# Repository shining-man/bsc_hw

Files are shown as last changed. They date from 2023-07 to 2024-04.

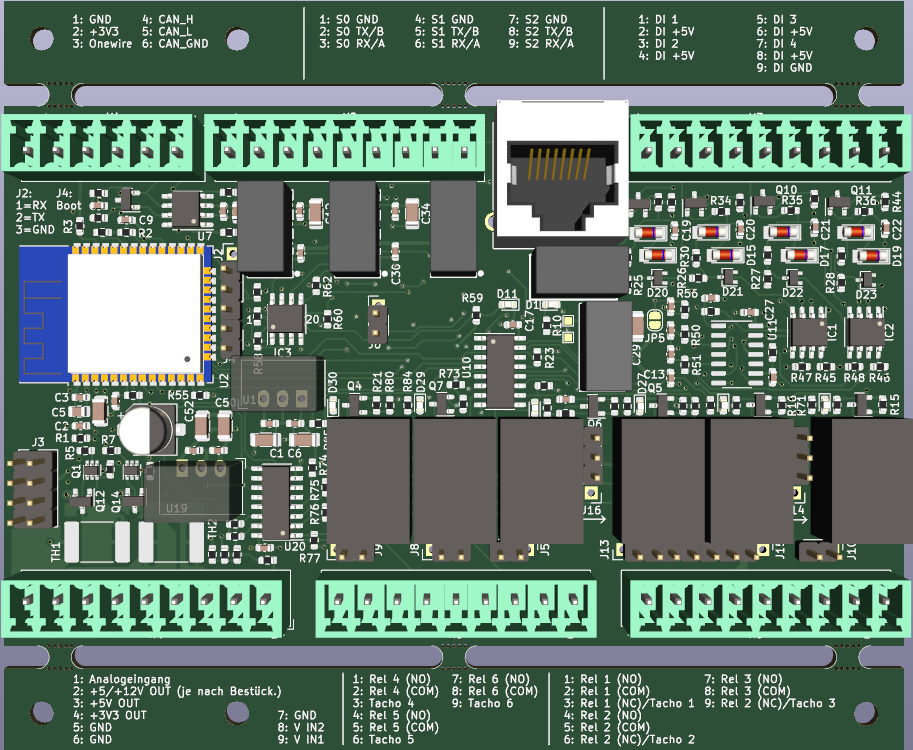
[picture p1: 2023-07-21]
img/bsc_3d.png

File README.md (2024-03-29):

# Battery safety controller (BSC)
This is the PCB for the Battery safety controller.<br>
More information in the wiki and in the discussions of the bsc_fw project.<br>
[BSC Project](https://github.com/shining-man/bsc_fw)<br>
[Wiki (German)](https://github.com/shining-man/bsc_fw/wiki)<br>
[Discussions](https://github.com/shining-man/bsc_fw/discussions)<br>
<br>
BSC_HW_TOP
BSC_HW_BOTTOM

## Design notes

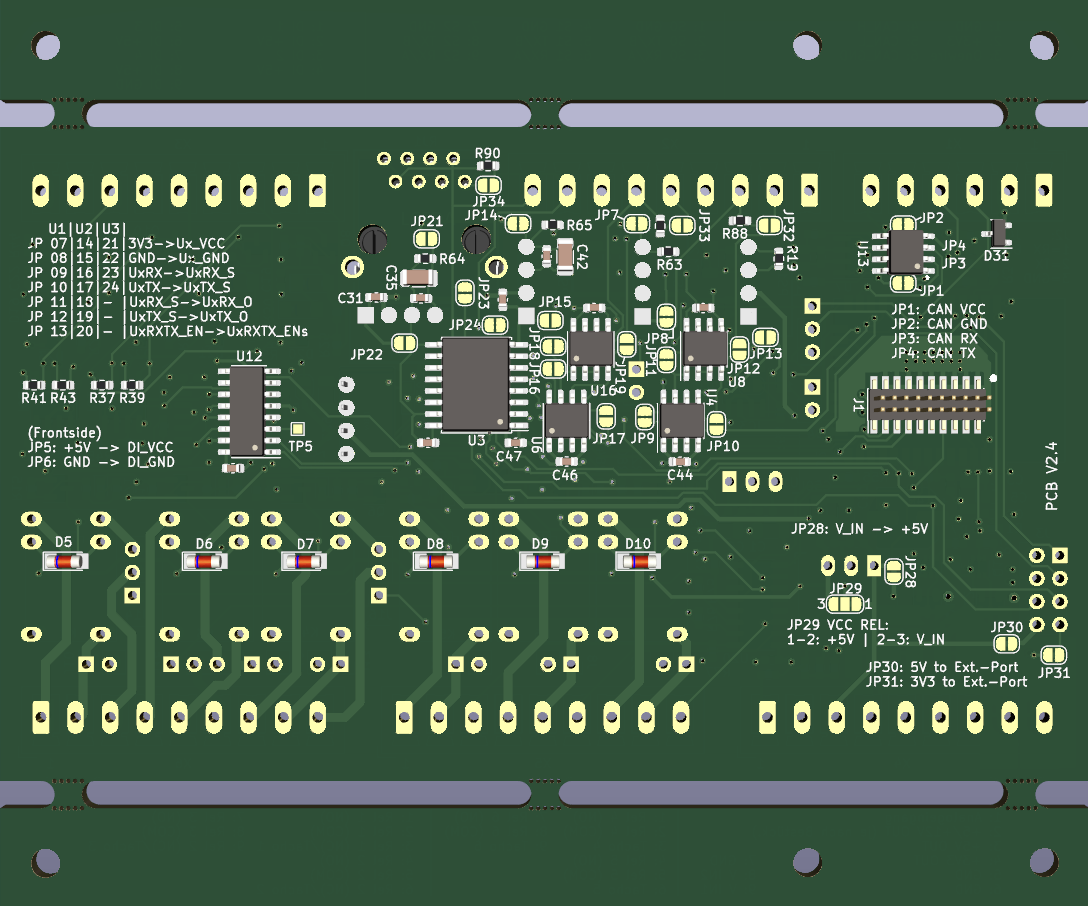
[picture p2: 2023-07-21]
img/bsc_bot.png

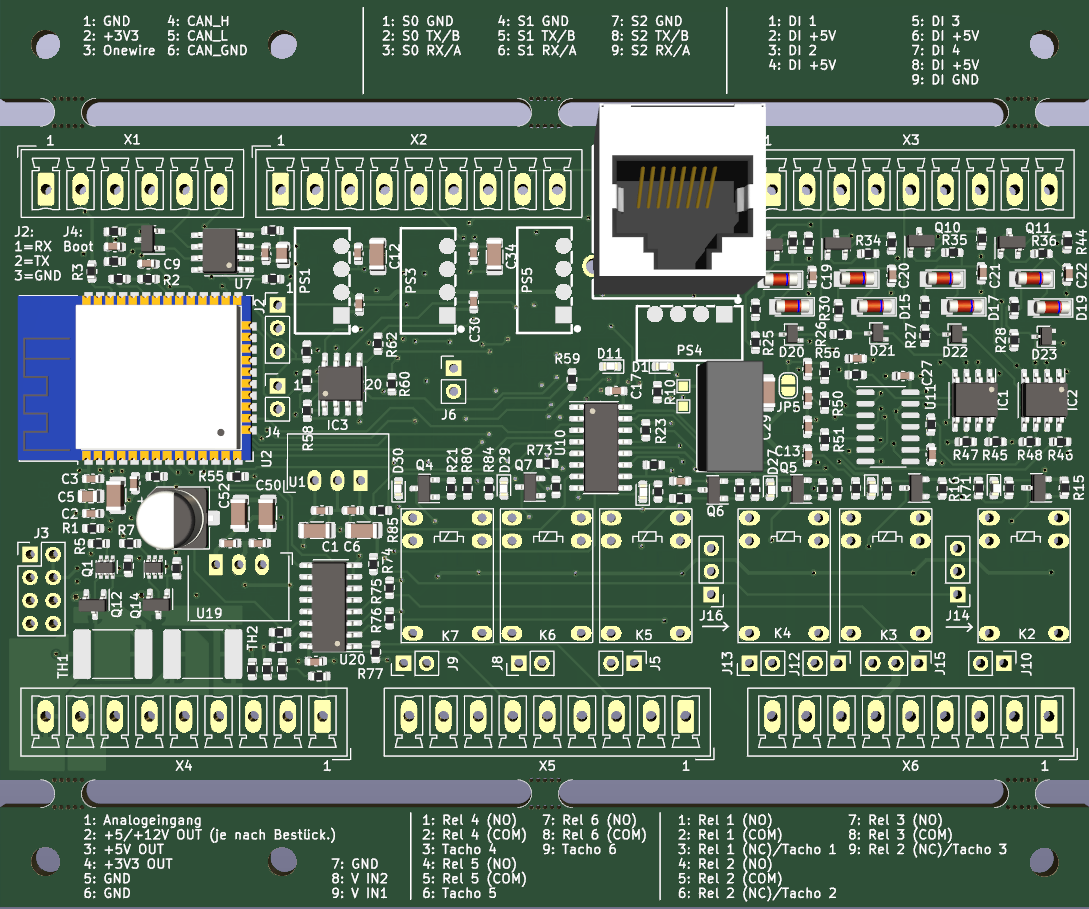
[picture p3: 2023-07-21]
img/bsc_top.png

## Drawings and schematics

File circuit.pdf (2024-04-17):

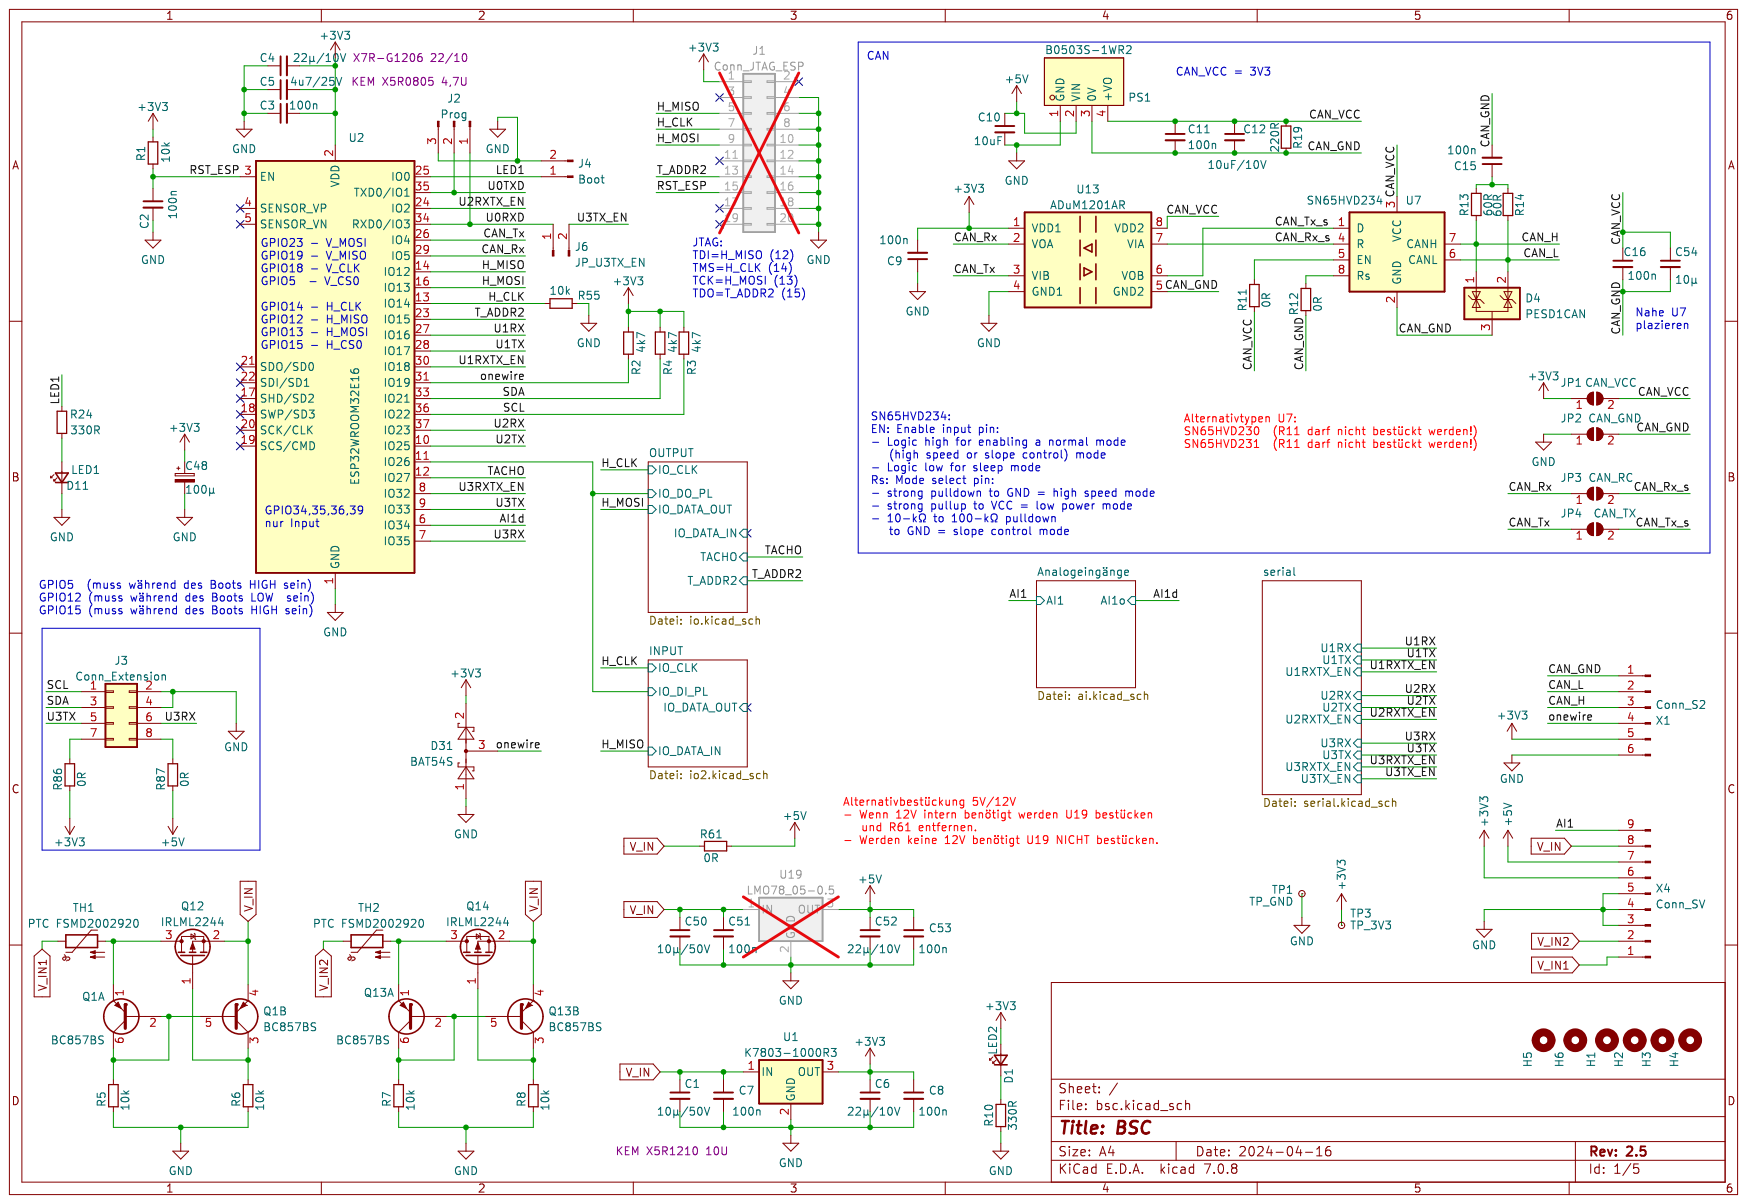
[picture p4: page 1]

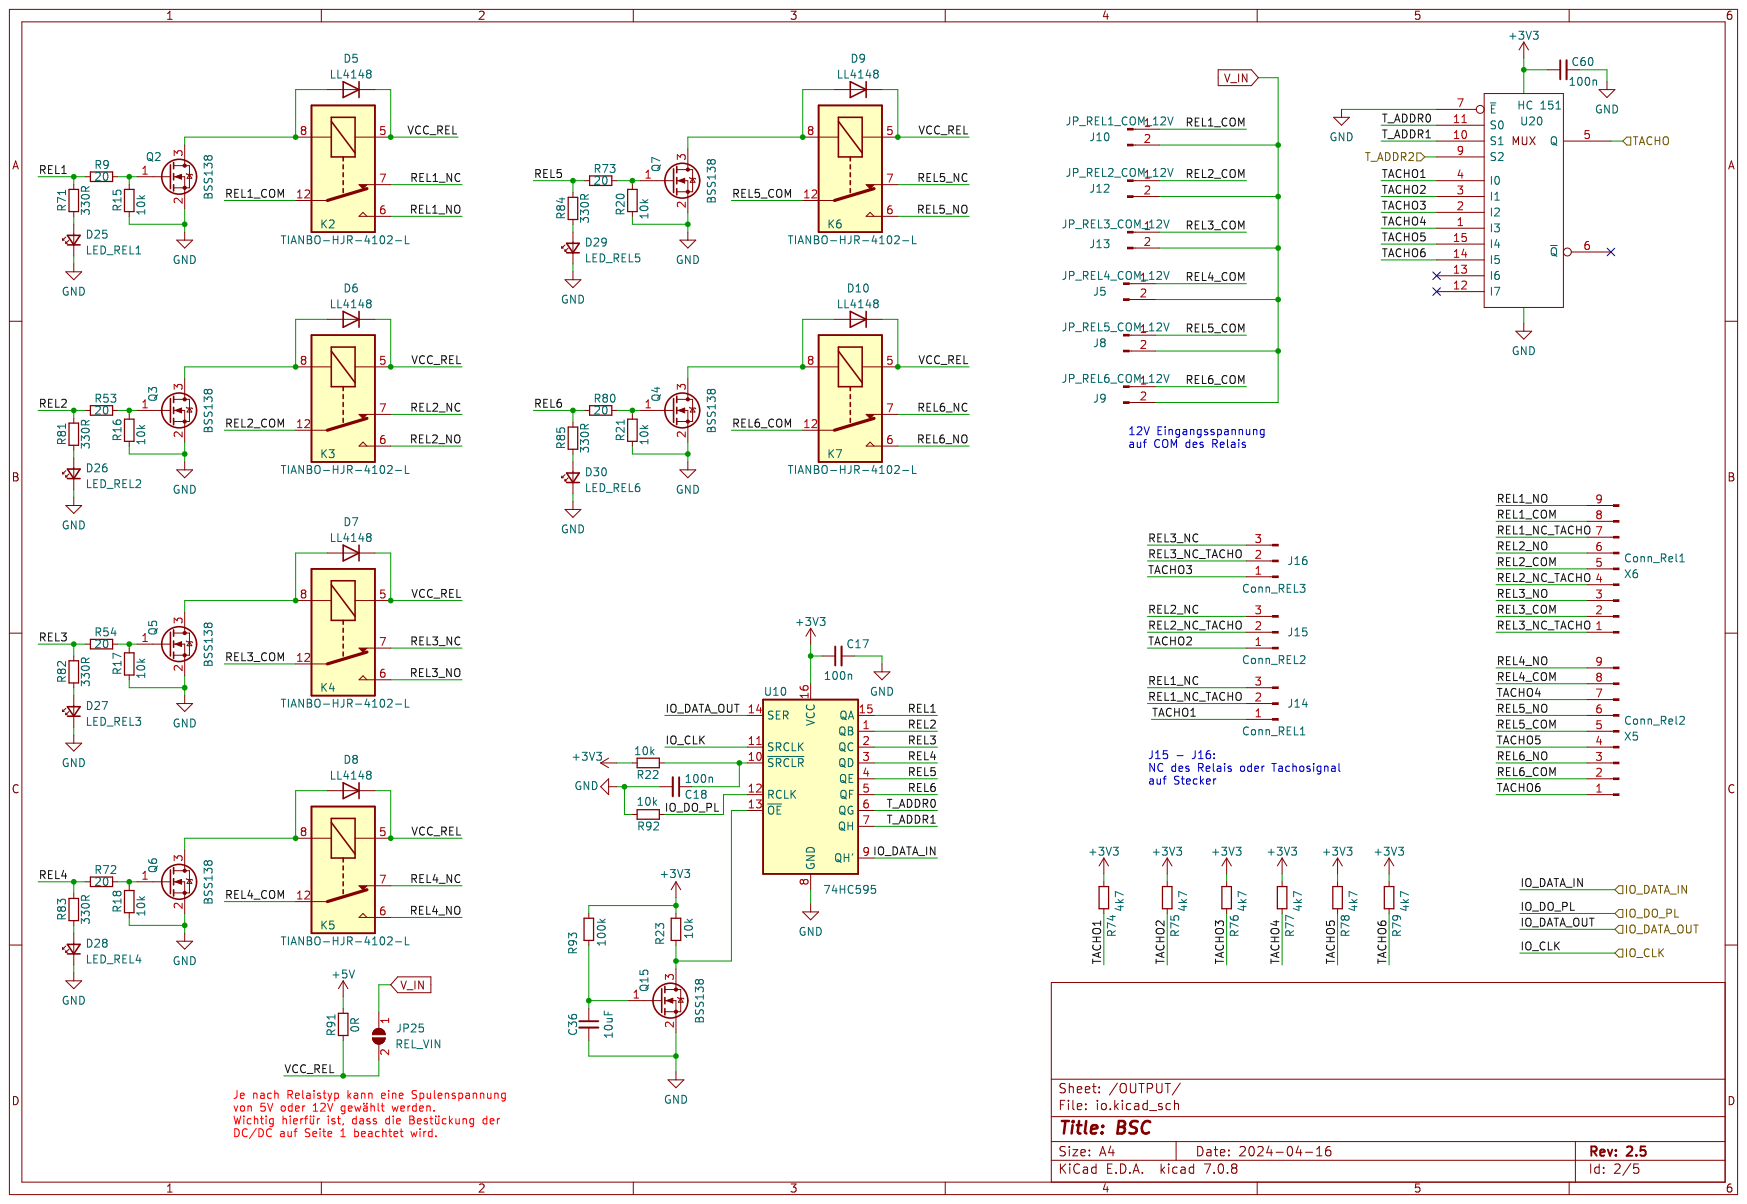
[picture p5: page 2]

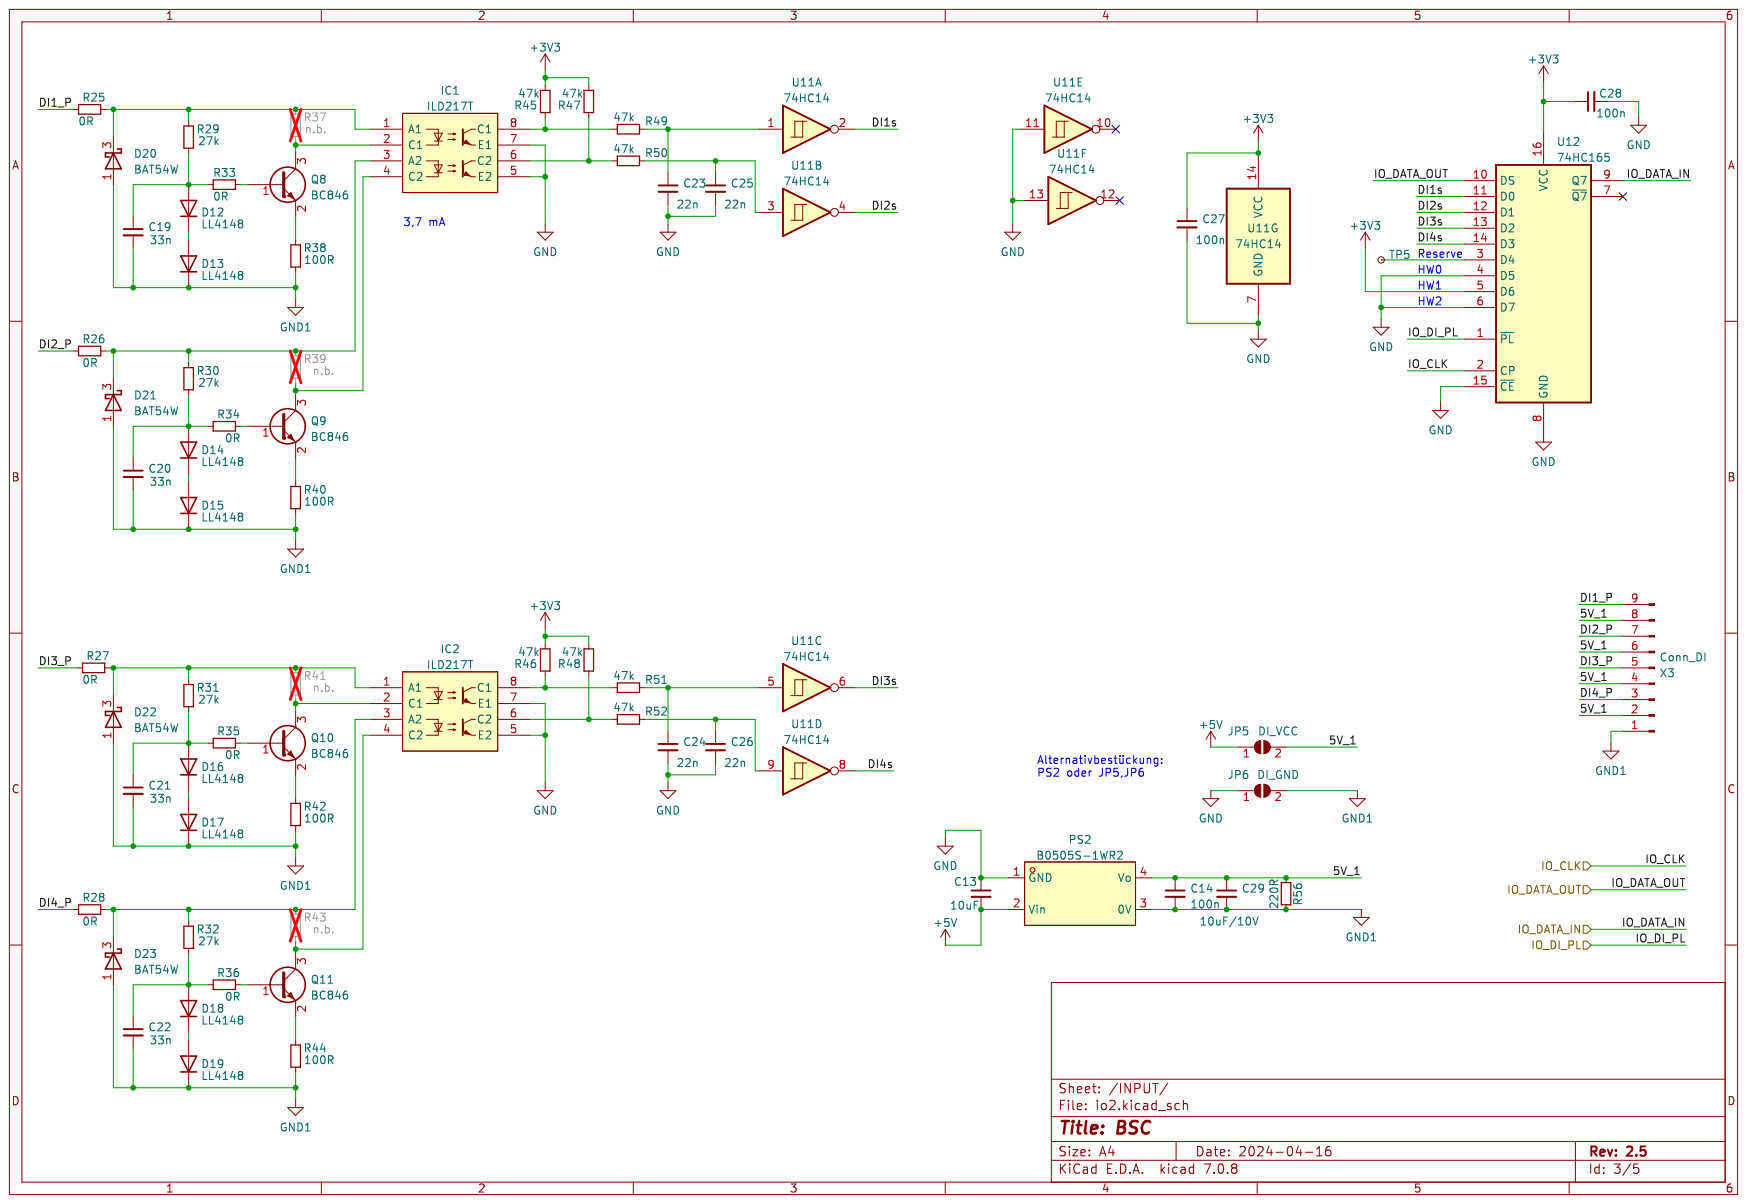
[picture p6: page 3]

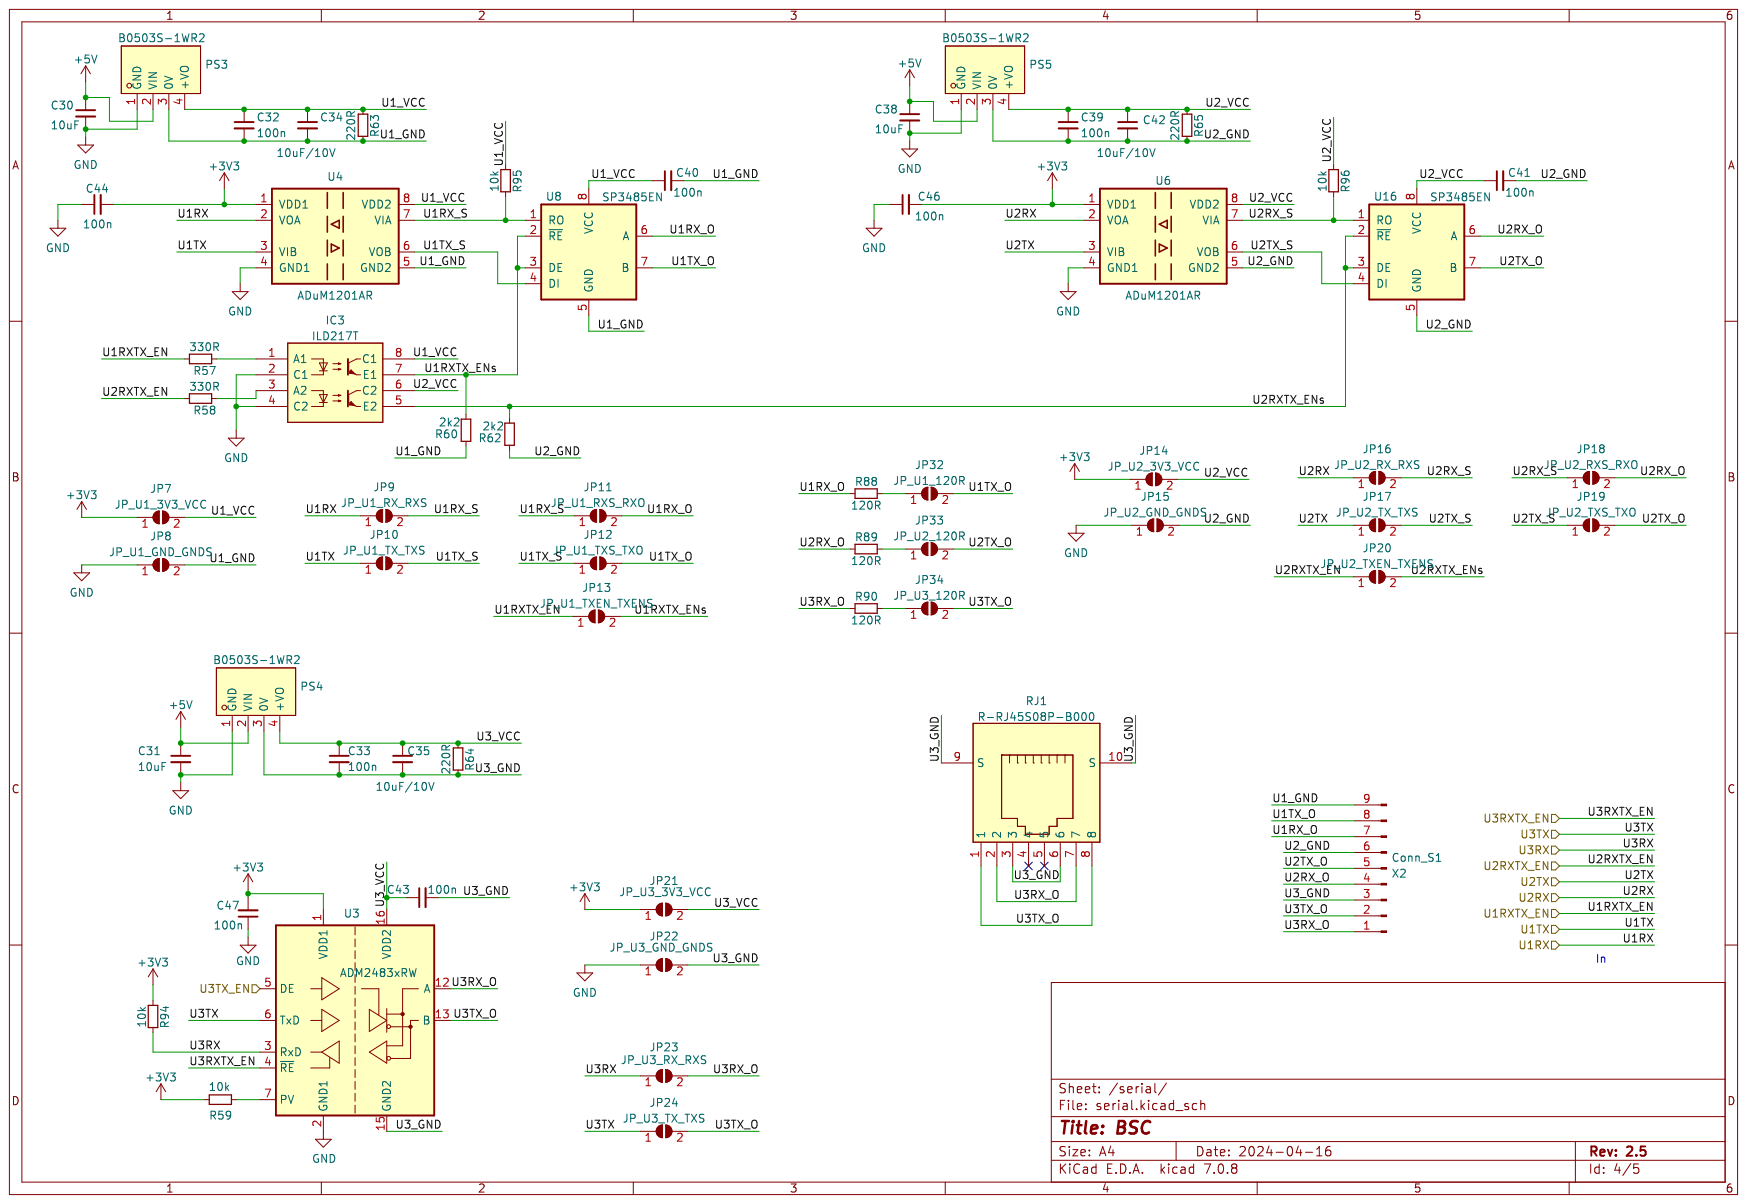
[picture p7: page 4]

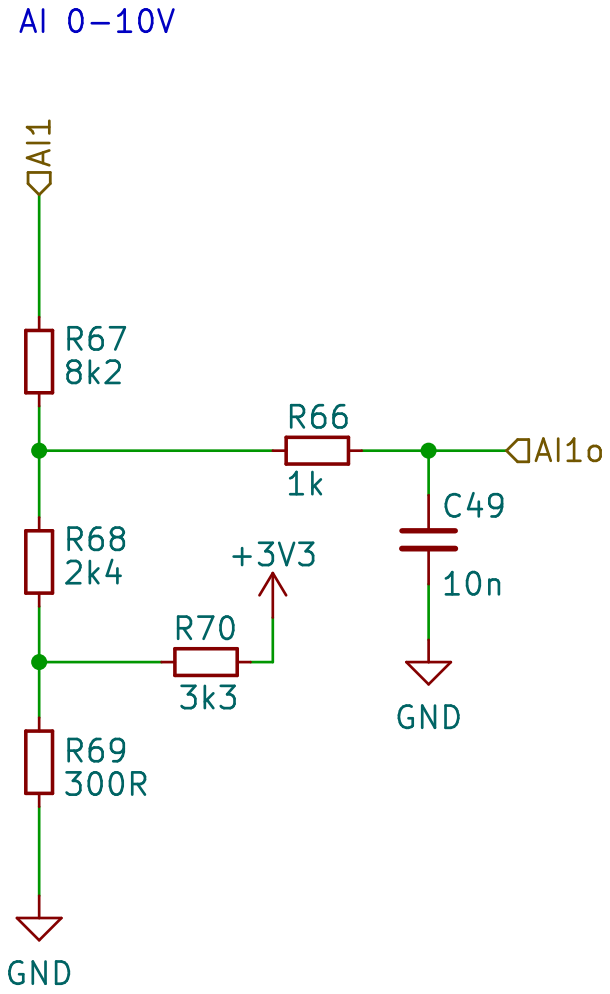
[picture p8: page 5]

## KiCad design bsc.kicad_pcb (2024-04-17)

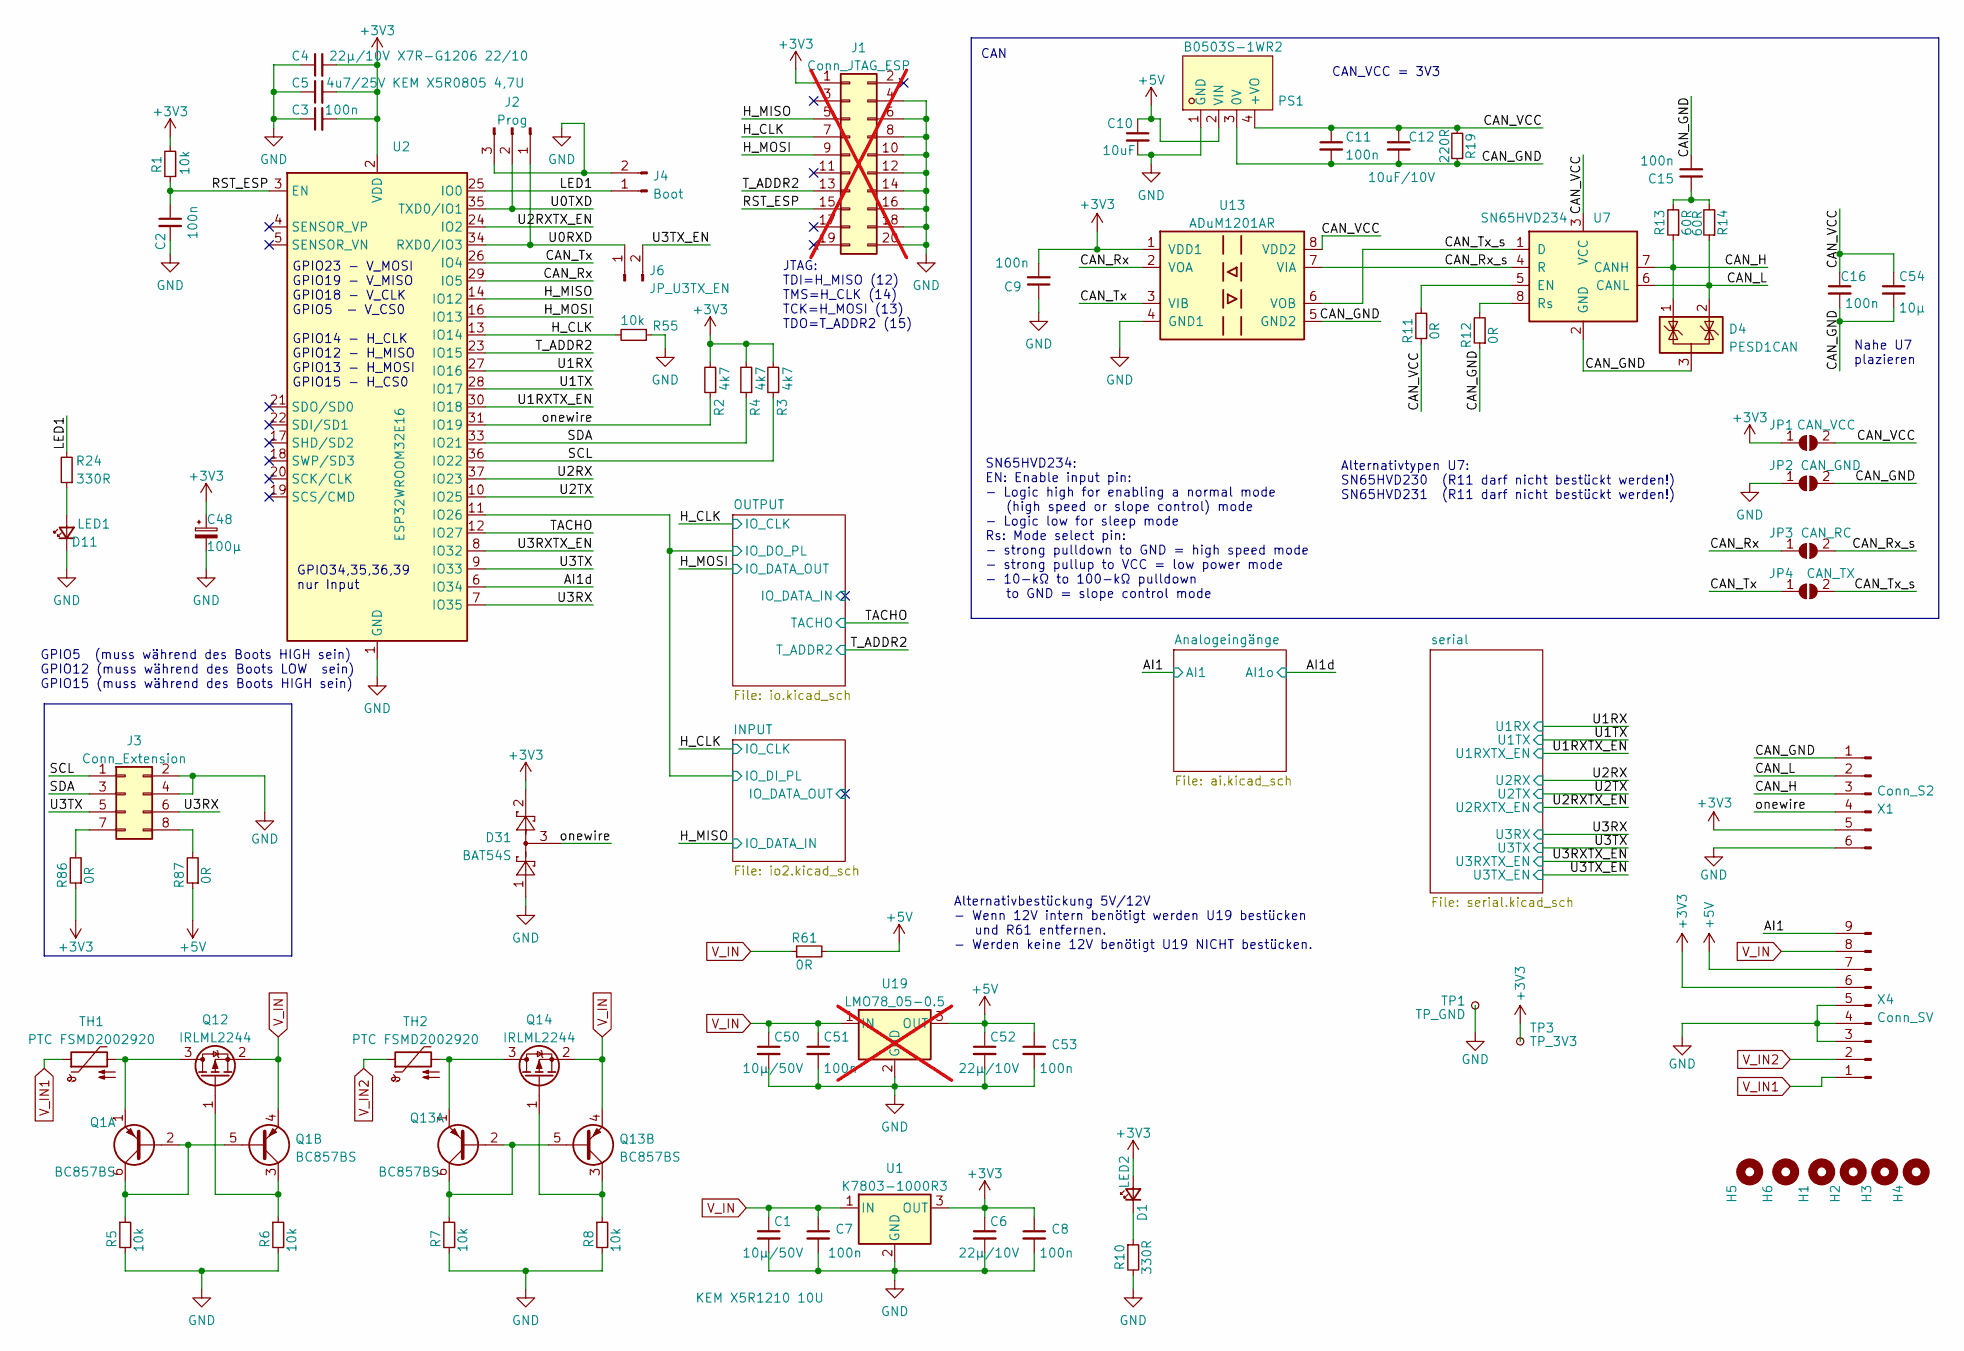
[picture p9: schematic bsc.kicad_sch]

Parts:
C1, C50: 10µ/50V; C_1206_3216Metric
C2, C3, C7, C8, C9, C11, C15, C16, C51, C53: 100n; C_0603_1608Metric
C4, C6, C52: 22µ/10V; C_1206_3216Metric
C5: 4u7/25V; C_0805_2012Metric
C10: 10uF; C_0603_1608Metric
C12: 10uF/10V; C_1206_3216Metric
C48: 100µ; CP_Elec_6.3x5.9
C54: 10µ; C_0805_2012Metric
D1: LED2; LED_0603_1608Metric
D4: PESD1CAN; SOT-23
D11: LED1; LED_0603_1608Metric
D31: BAT54S; SOT-23
H1, H2, H3, H4, H5, H6: MountingHole; MountingHole_3.2mm_M3
J1: Conn_JTAG_ESP; PinHeader_2x10_P1.27mm_Vertical_SMD; not fitted
J2: Prog; PinHeader_1x03_P2.54mm_Vertical_jlc
J3: Conn_Extension; PinHeader_2x04_P2.54mm_Vertical_jlc
J4: Boot; PinHeader_1x02_P2.54mm_Vertical_jlc
J6: JP_U3TX_EN; PinHeader_1x02_P2.54mm_Vertical_jlc
JP1: CAN_VCC; SolderJumper-2_P1.3mm_Open_RoundedPad1.0x1.5mm
JP2: CAN_GND; SolderJumper-2_P1.3mm_Open_RoundedPad1.0x1.5mm
JP3: CAN_RC; SolderJumper-2_P1.3mm_Open_RoundedPad1.0x1.5mm
JP4: CAN_TX; SolderJumper-2_P1.3mm_Open_RoundedPad1.0x1.5mm
PS1: B0503S-1WR2; PWRM-TH_DEXU_BXXXXS-1WR2; LCSC Part C5127059
Q1, Q13: BC857BS; SOT-363_SC-70-6
Q12, Q14: IRLML2244; SOT-23
R1, R5, R6, R7, R8, R55: 10k; R_0603_1608Metric
R2, R3, R4: 4k7; R_0603_1608Metric
R10, R24: 330R; R_0603_1608Metric
R11, R12, R61, R86, R87: 0R; R_0603_1608Metric
R13, R14: 60R; R_0603_1608Metric
R19: 220R; R_0805_2012Metric
TH1, TH2: PTC FSMD2002920; Fuse_2920_7451Metric
TP1: TP_GND; TestPoint_Pad_1.0x1.0mm
TP3: TP_3V3; TestPoint_Pad_1.0x1.0mm
U1: K7803-1000R3; Converter_DCDC_RECOM_R-78E-1.0; LCSC Part C111278
U2: ESP32WROOM32E16; ESP32-WROOM-32
U7: SN65HVD234; SOIC-8_3.9x4.9mm_P1.27mm
U13: ADuM1201AR; SOIC-8_3.9x4.9mm_P1.27mm
U19: LMO78_05-0.5; Converter_DCDC_RECOM_R-78E-1.0; not fitted
X1: Conn_S2; PhoenixContact_MCV_1,5_6-G-3.81_1x06_P3.81mm_Vertical
X4: Conn_SV; PhoenixContact_MCV_1,5_9-G-3.81_1x09_P3.81mm_Vertical

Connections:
+3V3: C3.2, C4.2, C5.2, C6.1, C8.1, C9.2, C48.1, D1.2 (A), D31.2, J1.1, JP1.1 (A), R1.2, R2.2, R3.2, R4.2, R86.1, TP3.1, U1.3 (OUT), U2.2 (VDD), U13.1 (VDD1), X1.5, X4.6; also elsewhere on the board
+5V: C10.1, C52.1, C53.1, PS1.2 (VIN), R61.2, R87.1, U19.3 (OUT), X4.7; also elsewhere on the board
/AI1: X4.9; also elsewhere on the board
/AI1d: U2.6 (IO34); also elsewhere on the board
/CAN_GND: C11.2, C12.2, C15.2, C16.2, C54.2, D4.3 (A), JP2.2 (B), PS1.3 (0V), R12.1, R19.1, U7.2 (GND), U13.5 (GND2), X1.1
/CAN_H: D4.1 (K), R13.1, U7.7 (CANH), X1.3
/CAN_L: D4.2 (K), R14.1, U7.6 (CANL), X1.2
/CAN_Rx: JP3.1 (A), U2.29 (IO5), U13.2 (VOA)
/CAN_Rx_s: JP3.2 (B), U7.4 (R), U13.7 (VIA)
/CAN_Tx: JP4.1 (A), U2.26 (IO4), U13.3 (VIB)
/CAN_Tx_s: JP4.2 (B), U7.1 (D), U13.6 (VOB)
/CAN_VCC: C11.1, C12.1, C16.1, C54.1, JP1.2 (B), PS1.4 (+VO), R11.1, R19.2, U7.3 (VCC), U13.8 (VDD2)
/H_CLK: J1.7, R55.2, U2.13 (IO14); also elsewhere on the board
/H_MISO: J1.5, U2.14 (IO12); also elsewhere on the board
/H_MOSI: J1.9, U2.16 (IO13); also elsewhere on the board
/INPUT/IO_DI_PL: U2.11 (IO26); also elsewhere on the board
/LED1: J4.1, R24.2, U2.25 (IO0)
/SCL: J3.1, R3.1, U2.36 (IO22)
/SDA: J3.3, R4.1, U2.33 (IO21)
/TACHO: U2.12 (IO27); also elsewhere on the board
/T_ADDR2: J1.13, U2.23 (IO15); also elsewhere on the board
/U0RXD: J2.1, J6.1, U2.34 (RXD0/IO3)
/U0TXD: J2.2, U2.35 (TXD0/IO1)
/U1RX: U2.27 (IO16); also elsewhere on the board
/U1RXTX_EN: U2.30 (IO18); also elsewhere on the board
/U1TX: U2.28 (IO17); also elsewhere on the board
/U2RX: U2.37 (IO23); also elsewhere on the board
/U2RXTX_EN: U2.24 (IO2); also elsewhere on the board
/U2TX: U2.10 (IO25); also elsewhere on the board
/U3RX: J3.6, U2.7 (IO35); also elsewhere on the board
/U3RXTX_EN: U2.8 (IO32); also elsewhere on the board
/U3TX: J3.5, U2.9 (IO33); also elsewhere on the board
/U3TX_EN: J6.2; also elsewhere on the board
/onewire: D31.3, R2.1, U2.31 (IO19), X1.4
GND: C1.2, C2.2, C3.1, C4.1, C5.1, C6.2, C7.2, C8.2, C9.1, C10.2, C48.2, C50.2, C51.2, C52.2, C53.2, D11.1 (K), D31.1, J1.4, J1.6, J1.8, J1.10, J1.12, J1.14, J1.16, J1.18, J1.20, J2.3, J3.2, J3.4, J4.2, JP2.1 (A), PS1.1 (GND), R5.2, R6.2, R7.2, R8.2, R10.2, R55.1, TP1.1, U1.2 (GND), U2.1 (GND), U2.15 (GND), U2.38 (GND), U2.39 (GND), U13.4 (GND1), U19.2 (GND), X1.6, X4.3, X4.4, X4.5; also elsewhere on the board
unnamed: C15.1, R13.2, R14.2
unnamed: D1.1 (K), R10.1
unnamed: D11.2 (A), R24.1
unnamed: J3.7, R86.2
unnamed: J3.8, R87.2
unnamed: Q1.2 (B1), Q1.5 (B2), Q1.6 (C1), R5.1
unnamed: Q1.1 (E1), Q12.3 (D), TH1.2
unnamed: Q1.3 (C2), Q12.1 (G), R6.1
unnamed: Q13.2 (B1), Q13.5 (B2), Q13.6 (C1), R7.1
unnamed: Q13.1 (E1), Q14.3 (D), TH2.2
unnamed: Q13.3 (C2), Q14.1 (G), R8.1
unnamed: R11.2, U7.5 (EN)
unnamed: R12.2, U7.8 (Rs)
V_IN: C1.1, C7.1, C50.1, C51.1, Q1.4 (E2), Q12.2 (S), Q13.4 (E2), Q14.2 (S), R61.1, U1.1 (IN), U19.1 (IN), X4.8; also elsewhere on the board
V_IN1: TH1.1, X4.1
V_IN2: TH2.1, X4.2

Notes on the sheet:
SN65HVD234: EN: Enable input pin: - Logic high for enabling a normal mode (high speed or slope control) mode - Logic low for sleep mode Rs: Mode select pin: - strong pulldown to GND = high speed mode - strong pullup to VCC = low power mode - 10-kΩ to 100-kΩ pulldown to GND = slope control mode
GPIO23 - V_MOSI GPIO19 - V_MISO GPIO18 - V_CLK GPIO5 - V_CS0 GPIO14 - H_CLK GPIO12 - H_MISO GPIO13 - H_MOSI GPIO15 - H_CS0
JTAG: TDI=H_MISO (12) TMS=H_CLK (14) TCK=H_MOSI (13) TDO=T_ADDR2 (15)
CAN
CAN_VCC = 3V3
Alternativtypen U7: SN65HVD230 (R11 darf nicht bestückt werden!) SN65HVD231 (R11 darf nicht bestückt werden!)
Nahe U7 plazieren
GPIO5 (muss während des Boots HIGH sein) GPIO12 (muss während des Boots LOW sein) GPIO15 (muss während des Boots HIGH sein)
Alternativbestückung 5V/12V - Wenn 12V intern benötigt werden U19 bestücken und R61 entfernen. - Werden keine 12V benötigt U19 NICHT bestücken.
GPIO34,35,36,39 nur Input

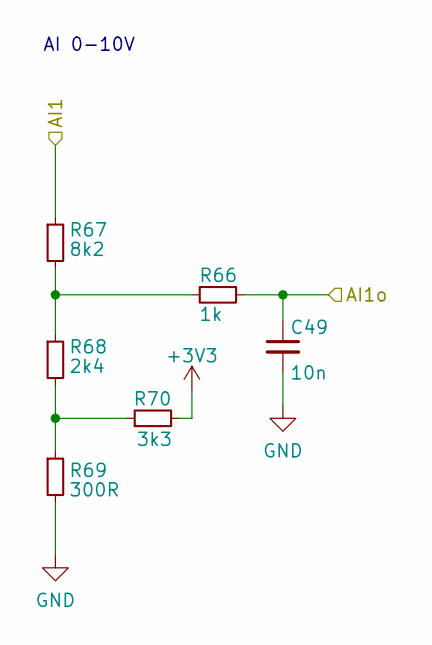
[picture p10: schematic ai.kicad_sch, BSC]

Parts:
C49: 10n; C_0603_1608Metric
R66: 1k; R_0603_1608Metric
R67: 8k2; R_0603_1608Metric
R68: 2k4; R_0603_1608Metric
R69: 300R; R_0603_1608Metric
R70: 3k3; R_0603_1608Metric

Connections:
+3V3: R70.2; also elsewhere on the board
/AI1: R67.1; also elsewhere on the board
/AI1d: C49.1, R66.1; also elsewhere on the board
GND: C49.2, R69.2; also elsewhere on the board
unnamed: R66.2, R67.2, R68.1
unnamed: R68.2, R69.1, R70.1

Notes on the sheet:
AI 0-10V

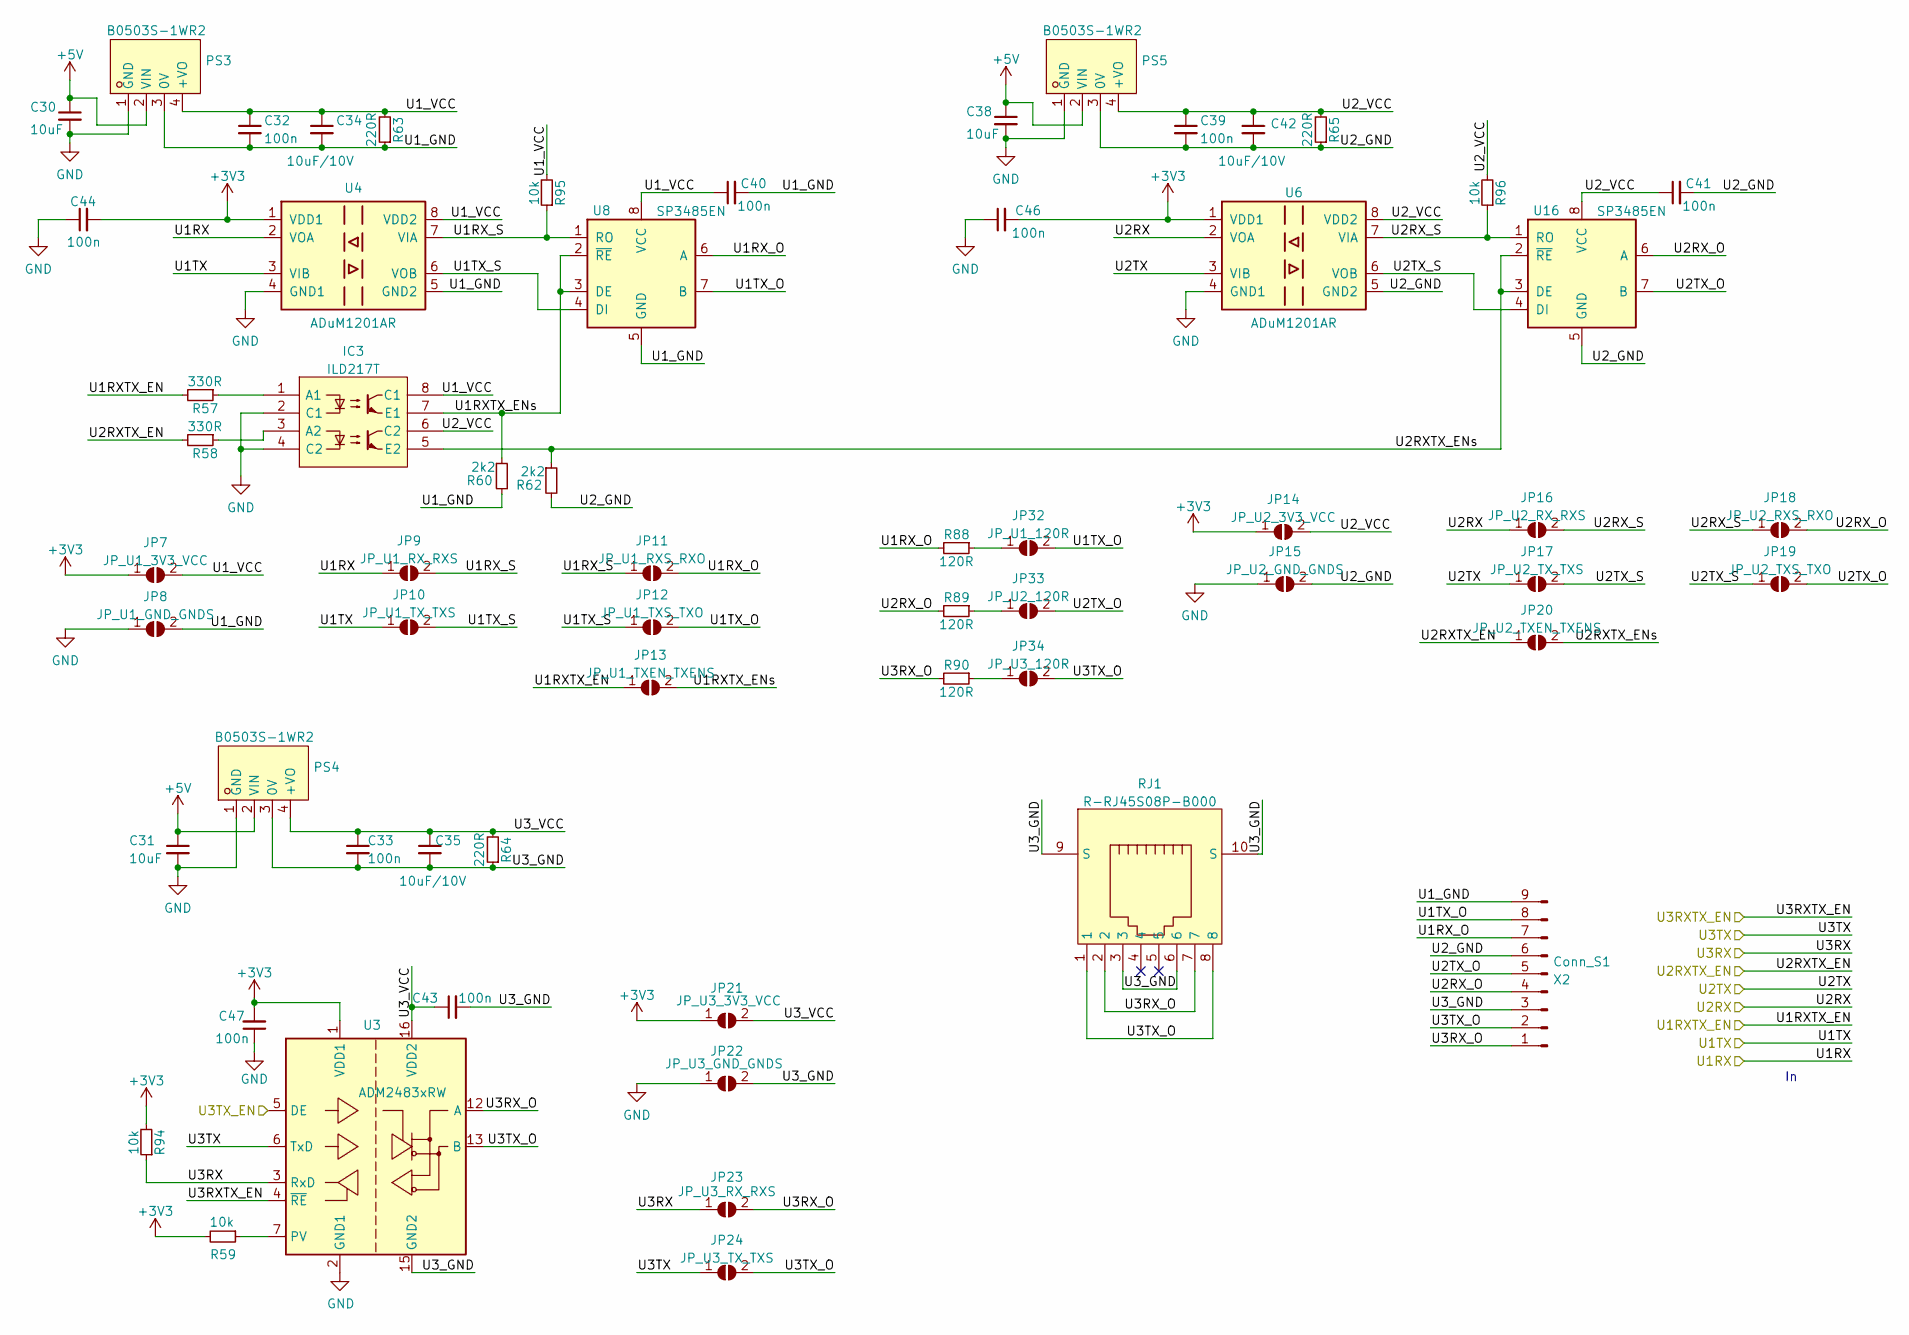
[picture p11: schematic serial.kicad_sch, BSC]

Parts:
C30, C31, C38: 10uF; C_0603_1608Metric
C32, C33, C39, C40, C41, C43, C44, C46, C47: 100n; C_0603_1608Metric
C34, C35, C42: 10uF/10V; C_1206_3216Metric
IC3: ILD217T; SOIC-8_3.9x4.9mm_P1.27mm; Mouser Part Number 782-ILD217T
JP7: JP_U1_3V3_VCC; SolderJumper-2_P1.3mm_Open_RoundedPad1.0x1.5mm
JP8: JP_U1_GND_GNDS; SolderJumper-2_P1.3mm_Open_RoundedPad1.0x1.5mm
JP9: JP_U1_RX_RXS; SolderJumper-2_P1.3mm_Open_RoundedPad1.0x1.5mm
JP10: JP_U1_TX_TXS; SolderJumper-2_P1.3mm_Open_RoundedPad1.0x1.5mm
JP11: JP_U1_RXS_RXO; SolderJumper-2_P1.3mm_Open_RoundedPad1.0x1.5mm
JP12: JP_U1_TXS_TXO; SolderJumper-2_P1.3mm_Open_RoundedPad1.0x1.5mm
JP13: JP_U1_TXEN_TXENS; SolderJumper-2_P1.3mm_Open_RoundedPad1.0x1.5mm
JP14: JP_U2_3V3_VCC; SolderJumper-2_P1.3mm_Open_RoundedPad1.0x1.5mm
JP15: JP_U2_GND_GNDS; SolderJumper-2_P1.3mm_Open_RoundedPad1.0x1.5mm
JP16: JP_U2_RX_RXS; SolderJumper-2_P1.3mm_Open_RoundedPad1.0x1.5mm
JP17: JP_U2_TX_TXS; SolderJumper-2_P1.3mm_Open_RoundedPad1.0x1.5mm
JP18: JP_U2_RXS_RXO; SolderJumper-2_P1.3mm_Open_RoundedPad1.0x1.5mm
JP19: JP_U2_TXS_TXO; SolderJumper-2_P1.3mm_Open_RoundedPad1.0x1.5mm
JP20: JP_U2_TXEN_TXENS; SolderJumper-2_P1.3mm_Open_RoundedPad1.0x1.5mm
JP21: JP_U3_3V3_VCC; SolderJumper-2_P1.3mm_Open_RoundedPad1.0x1.5mm
JP22: JP_U3_GND_GNDS; SolderJumper-2_P1.3mm_Open_RoundedPad1.0x1.5mm
JP23: JP_U3_RX_RXS; SolderJumper-2_P1.3mm_Open_RoundedPad1.0x1.5mm
JP24: JP_U3_TX_TXS; SolderJumper-2_P1.3mm_Open_RoundedPad1.0x1.5mm
JP32: JP_U1_120R; SolderJumper-2_P1.3mm_Open_RoundedPad1.0x1.5mm
JP33: JP_U2_120R; SolderJumper-2_P1.3mm_Open_RoundedPad1.0x1.5mm
JP34: JP_U3_120R; SolderJumper-2_P1.3mm_Open_RoundedPad1.0x1.5mm
PS3, PS4, PS5: B0503S-1WR2; PWRM-TH_DEXU_BXXXXS-1WR2; LCSC Part C5127059
R57, R58: 330R; R_0603_1608Metric
R59, R94, R95, R96: 10k; R_0603_1608Metric
R60, R62: 2k2; R_0603_1608Metric
R63, R64, R65: 220R; R_0805_2012Metric
R88, R89, R90: 120R; R_0603_1608Metric
RJ1: R-RJ45S08P-B000; RJ45-TH_R-RJ45S08P-B000; LCSC Part C386763
U3: ADM2483xRW; SOIC-16W_7.5x10.3mm_P1.27mm; PartNumber ADM2483BRWZ-REEL; LCSCStockCode C9637
U4, U6: ADuM1201AR; SOIC-8_3.9x4.9mm_P1.27mm
U8, U16: SP3485EN; SOIC-8_3.9x4.9mm_P1.27mm
X2: Conn_S1; PhoenixContact_MCV_1,5_9-G-3.81_1x09_P3.81mm_Vertical

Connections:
+3V3: C44.2, C46.2, C47.2, JP7.1 (A), JP14.1 (A), JP21.1 (A), R59.2, R94.2, U3.1 (VDD1), U4.1 (VDD1), U6.1 (VDD1); also elsewhere on the board
+5V: C30.1, C31.1, C38.1, PS3.2 (VIN), PS4.2 (VIN), PS5.2 (VIN); also elsewhere on the board
/U1RX: JP9.1 (A), U4.2 (VOA); also elsewhere on the board
/U1RXTX_EN: JP13.1 (A), R57.2; also elsewhere on the board
/U1TX: JP10.1 (A), U4.3 (VIB); also elsewhere on the board
/U2RX: JP16.1 (A), U6.2 (VOA); also elsewhere on the board
/U2RXTX_EN: JP20.1 (A), R58.2; also elsewhere on the board
/U2TX: JP17.1 (A), U6.3 (VIB); also elsewhere on the board
/U3RX: JP23.1 (A), R94.1, U3.3 (RxD); also elsewhere on the board
/U3RXTX_EN: U3.4 (~RE); also elsewhere on the board
/U3TX: JP24.1 (A), U3.6 (TxD); also elsewhere on the board
/U3TX_EN: U3.5 (DE); also elsewhere on the board
/serial/U1RXTX_ENs: IC3.7 (E1), JP13.2 (B), R60.1, U8.2 (~RE), U8.3 (DE)
/serial/U1RX_O: JP11.2 (B), R88.2, U8.6 (A), X2.7
/serial/U1RX_S: JP9.2 (B), JP11.1 (A), R95.1, U4.7 (VIA), U8.1 (RO)
/serial/U1TX_O: JP12.2 (B), JP32.2 (B), U8.7 (B), X2.8
/serial/U1TX_S: JP10.2 (B), JP12.1 (A), U4.6 (VOB), U8.4 (DI)
/serial/U1_GND: C32.2, C34.2, C40.2, JP8.2 (B), PS3.3 (0V), R60.2, R63.1, U4.5 (GND2), U8.5 (GND), X2.9
/serial/U1_VCC: C32.1, C34.1, C40.1, IC3.8 (C1), JP7.2 (B), PS3.4 (+VO), R63.2, R95.2, U4.8 (VDD2), U8.8 (VCC)
/serial/U2RXTX_ENs: IC3.5 (E2), JP20.2 (B), R62.1, U16.2 (~RE), U16.3 (DE)
/serial/U2RX_O: JP18.2 (B), R89.2, U16.6 (A), X2.4
/serial/U2RX_S: JP16.2 (B), JP18.1 (A), R96.1, U6.7 (VIA), U16.1 (RO)
/serial/U2TX_O: JP19.2 (B), JP33.2 (B), U16.7 (B), X2.5
/serial/U2TX_S: JP17.2 (B), JP19.1 (A), U6.6 (VOB), U16.4 (DI)
/serial/U2_GND: C39.2, C41.2, C42.2, JP15.2 (B), PS5.3 (0V), R62.2, R65.1, U6.5 (GND2), U16.5 (GND), X2.6
/serial/U2_VCC: C39.1, C41.1, C42.1, IC3.6 (C2), JP14.2 (B), PS5.4 (+VO), R65.2, R96.2, U6.8 (VDD2), U16.8 (VCC)
/serial/U3RX_O: JP23.2 (B), R90.2, RJ1.2, RJ1.7, U3.12 (A), X2.1
/serial/U3TX_O: JP24.2 (B), JP34.2 (B), RJ1.1, RJ1.8, U3.13 (B), X2.2
/serial/U3_GND: C33.2, C35.2, C43.2, JP22.2 (B), PS4.3 (0V), R64.1, RJ1.3, RJ1.6, RJ1.9 (S), RJ1.10 (S), U3.9 (GND2), U3.15 (GND2), X2.3
/serial/U3_VCC: C33.1, C35.1, C43.1, JP21.2 (B), PS4.4 (+VO), R64.2, U3.16 (VDD2)
GND: C30.2, C31.2, C38.2, C44.1, C46.1, C47.1, IC3.2 (C1), IC3.4 (C2), JP8.1 (A), JP15.1 (A), JP22.1 (A), PS3.1 (GND), PS4.1 (GND), PS5.1 (GND), U3.2 (GND1), U3.8 (GND1), U4.4 (GND1), U6.4 (GND1); also elsewhere on the board
unnamed: IC3.1 (A1), R57.1
unnamed: IC3.3 (A2), R58.1
unnamed: JP32.1 (A), R88.1
unnamed: JP33.1 (A), R89.1
unnamed: JP34.1 (A), R90.1
unnamed: R59.1, U3.7 (PV)

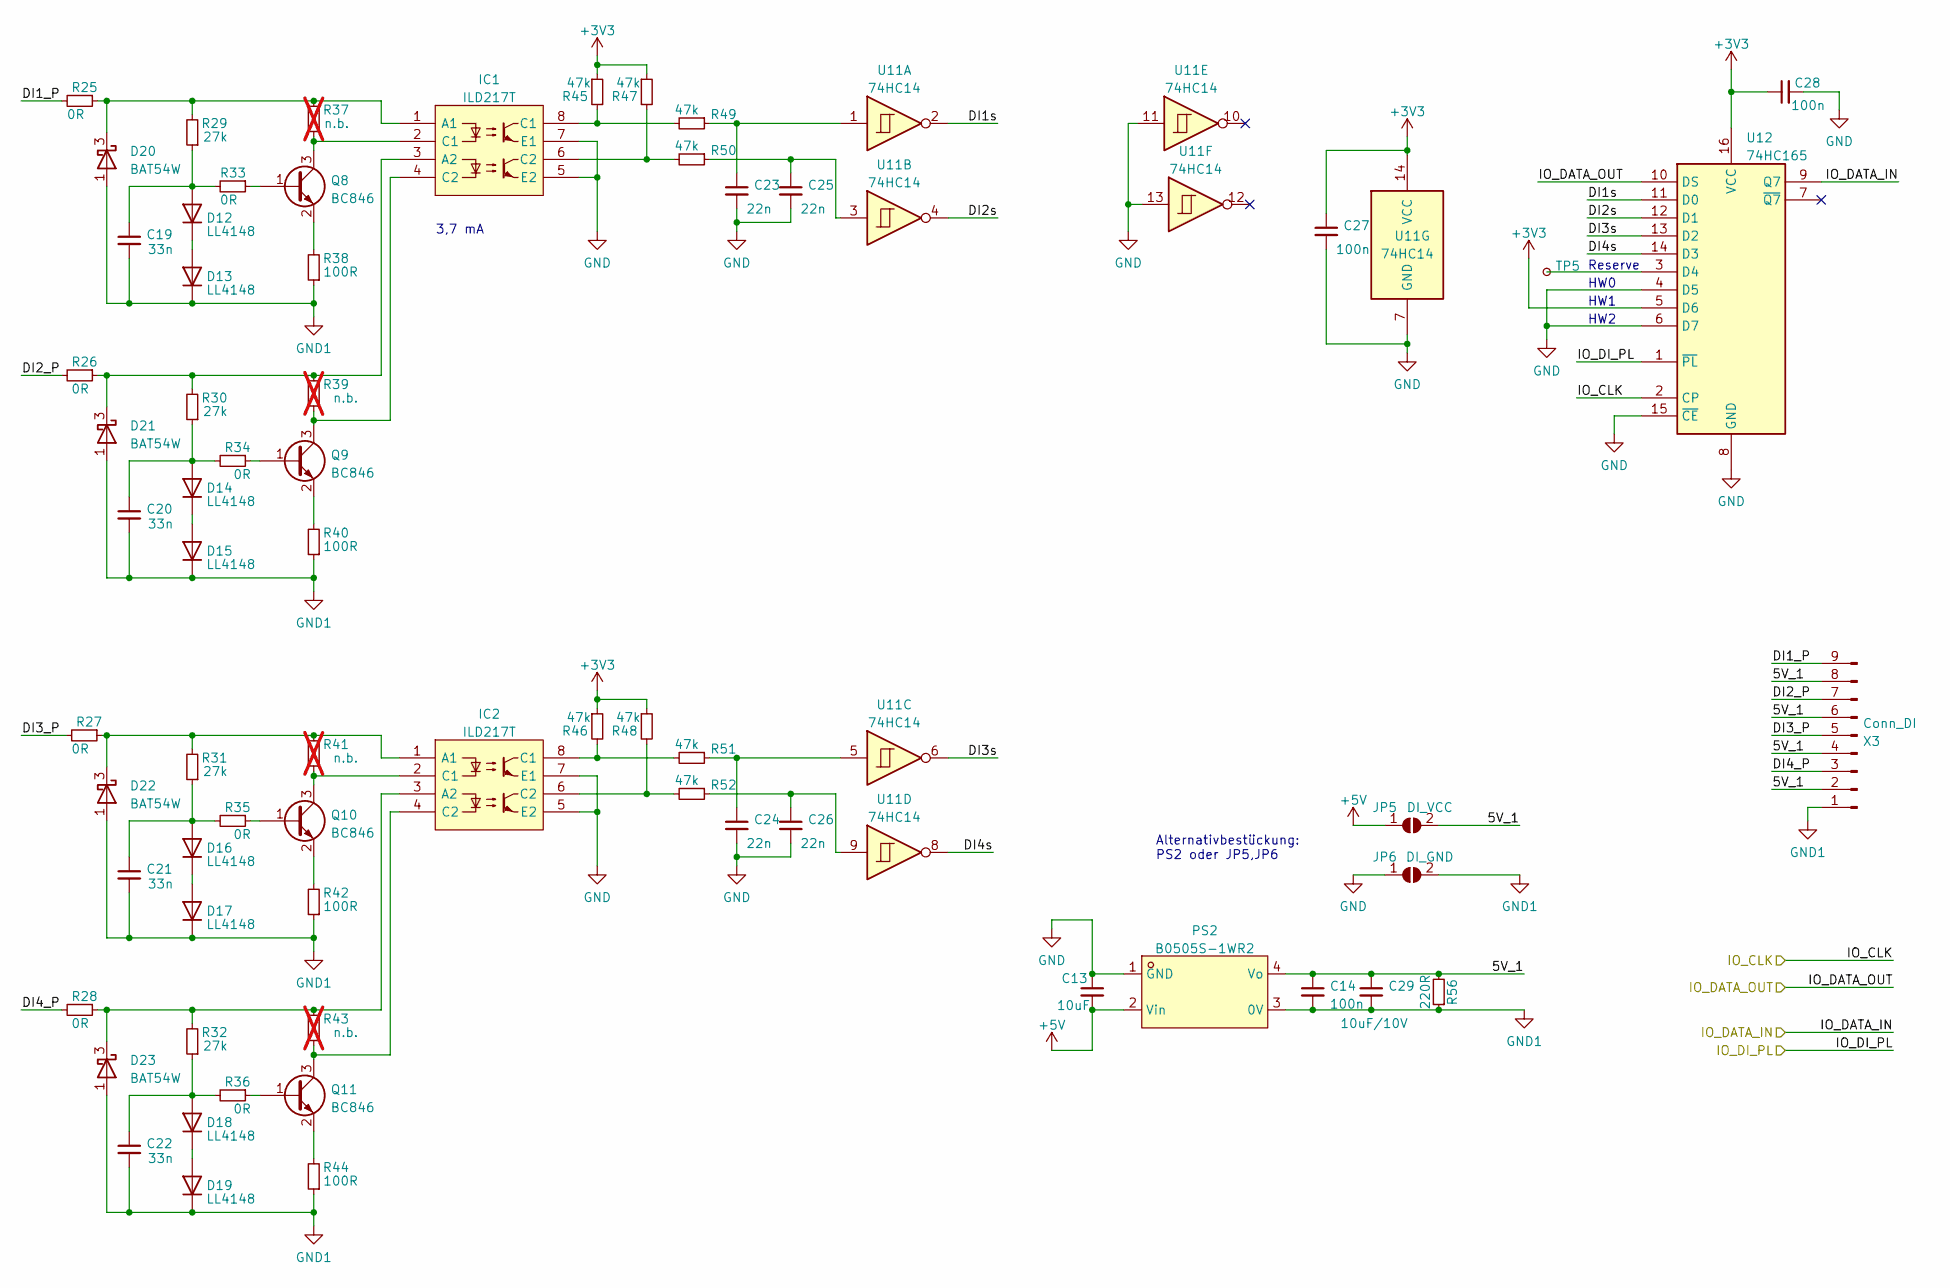
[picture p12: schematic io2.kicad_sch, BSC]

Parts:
C13: 10uF; C_0603_1608Metric
C14, C27, C28: 100n; C_0603_1608Metric
C19, C20, C21, C22: 33n; C_0603_1608Metric
C23, C24, C25, C26: 22n; C_0603_1608Metric
C29: 10uF/10V; C_1206_3216Metric
D12, D13, D14, D15, D16, D17, D18, D19: LL4148; D_MiniMELF
D20, D21, D22, D23: BAT54W; SOT-323_SC-70
IC1, IC2: ILD217T; SOIC-8_3.9x4.9mm_P1.27mm; Mouser Part Number 782-ILD217T
JP5: DI_VCC; SolderJumper-2_P1.3mm_Open_RoundedPad1.0x1.5mm
JP6: DI_GND; SolderJumper-2_P1.3mm_Open_RoundedPad1.0x1.5mm
PS2: B0505S-1WR2; PWRM-TH_BXXXXS-1WR3; LCSC Part C909796
Q8, Q9, Q10, Q11: BC846; SOT-23
R25, R26, R27, R28, R33, R34, R35, R36: 0R; R_0603_1608Metric
R29, R30, R31, R32: 27k; R_0603_1608Metric
R37, R39, R41, R43: n.b.; R_0603_1608Metric; not fitted
R38, R40, R42, R44: 100R; R_0603_1608Metric
R45, R46, R47, R48, R49, R50, R51, R52: 47k; R_0603_1608Metric
R56: 220R; R_0805_2012Metric
TP5: TP; TestPoint_Pad_1.0x1.0mm
U11: 74HC14; SO-14_3.9x8.65mm_P1.27mm
U12: 74HC165; SOIC-16_3.9x9.9mm_P1.27mm
X3: Conn_DI; PhoenixContact_MCV_1,5_9-G-3.81_1x09_P3.81mm_Vertical

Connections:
+3V3: C27.1, C28.1, R45.1, R46.1, R47.1, R48.1, U11.14 (VCC), U12.5 (D6), U12.16 (VCC); also elsewhere on the board
+5V: C13.2, JP5.1 (A), PS2.2 (Vin); also elsewhere on the board
/H_CLK: U12.2 (CP); also elsewhere on the board
/H_MISO: U12.9 (Q7); also elsewhere on the board
/INPUT/5V_1: C14.1, C29.1, JP5.2 (B), PS2.4 (Vo), R56.2, X3.2, X3.4, X3.6, X3.8
/INPUT/DI1_P: R25.2, X3.9
/INPUT/DI1s: U11.2, U12.11 (D0)
/INPUT/DI2_P: R26.2, X3.7
/INPUT/DI2s: U11.4, U12.12 (D1)
/INPUT/DI3_P: R27.2, X3.5
/INPUT/DI3s: U11.6, U12.13 (D2)
/INPUT/DI4_P: R28.2, X3.3
/INPUT/DI4s: U11.8, U12.14 (D3)
/INPUT/IO_DATA_OUT: U12.10 (DS)
/INPUT/IO_DI_PL: U12.1 (~PL); also elsewhere on the board
GND: C13.1, C23.2, C24.2, C25.2, C26.2, C27.2, C28.2, IC1.5 (E2), IC1.7 (E1), IC2.5 (E2), IC2.7 (E1), JP6.1 (A), PS2.1 (GND), U11.7 (GND), U11.11, U11.13, U12.4 (D5), U12.6 (D7), U12.8 (GND), U12.15 (~CE); also elsewhere on the board
GND1: C14.2, C19.2, C20.2, C21.2, C22.2, C29.2, D13.1 (K), D15.1 (K), D17.1 (K), D19.1 (K), D20.1 (A), D21.1 (A), D22.1 (A), D23.1 (A), JP6.2 (B), PS2.3 (0V), R38.1, R40.1, R42.1, R44.1, R56.1, X3.1
unnamed: C23.1, R49.1, U11.1
unnamed: C24.1, R51.1, U11.5
unnamed: C25.1, R50.1, U11.3
unnamed: C26.1, R52.1, U11.9
unnamed: C19.1, D12.2 (A), R29.1, R33.2
unnamed: D12.1 (K), D13.2 (A)
unnamed: C20.1, D14.2 (A), R30.1, R34.2
unnamed: D14.1 (K), D15.2 (A)
unnamed: C21.1, D16.2 (A), R31.1, R35.2
unnamed: D16.1 (K), D17.2 (A)
unnamed: C22.1, D18.2 (A), R32.1, R36.2
unnamed: D18.1 (K), D19.2 (A)
unnamed: D20.3 (K), IC1.1 (A1), R25.1, R29.2, R37.2
unnamed: D21.3 (K), IC1.3 (A2), R26.1, R30.2, R39.2
unnamed: D22.3 (K), IC2.1 (A1), R27.1, R31.2, R41.2
unnamed: D23.3 (K), IC2.3 (A2), R28.1, R32.2, R43.2
unnamed: IC1.8 (C1), R45.2, R49.2
unnamed: IC1.6 (C2), R47.2, R50.2
unnamed: IC2.8 (C1), R46.2, R51.2
unnamed: IC2.6 (C2), R48.2, R52.2
unnamed: Q8.1 (B), R33.1
unnamed: IC1.2 (C1), Q8.3 (C), R37.1
unnamed: Q8.2 (E), R38.2
unnamed: Q9.1 (B), R34.1
unnamed: IC1.4 (C2), Q9.3 (C), R39.1
unnamed: Q9.2 (E), R40.2
unnamed: Q10.1 (B), R35.1
unnamed: IC2.2 (C1), Q10.3 (C), R41.1
unnamed: Q10.2 (E), R42.2
unnamed: Q11.1 (B), R36.1
unnamed: IC2.4 (C2), Q11.3 (C), R43.1
unnamed: Q11.2 (E), R44.2
unnamed: TP5.1, U12.3 (D4)

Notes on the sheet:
Reserve
HW0
HW2
HW1
3,7 mA
Alternativbestückung: PS2 oder JP5,JP6

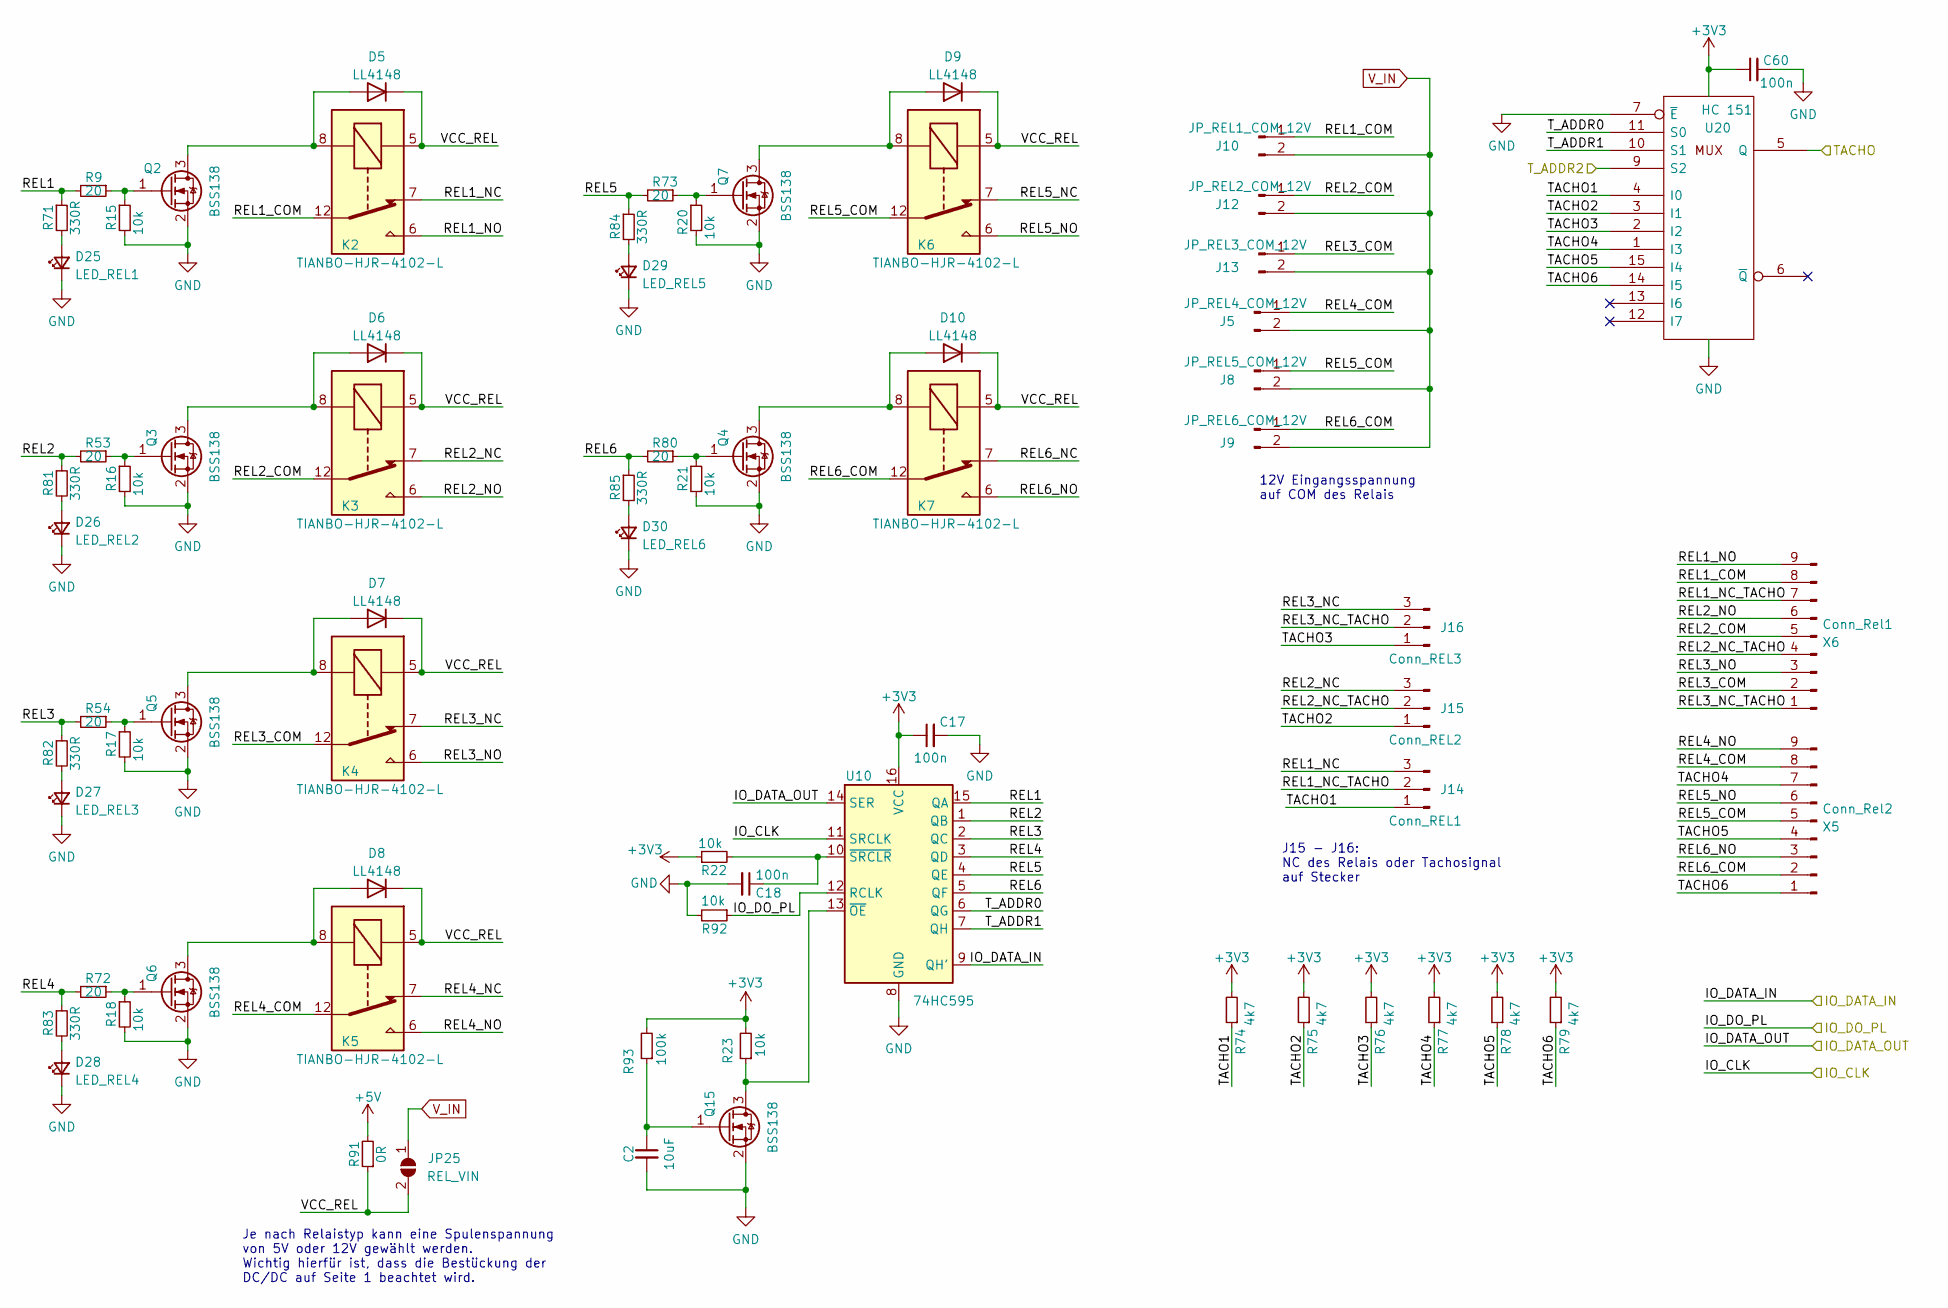
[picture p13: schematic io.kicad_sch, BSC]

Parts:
C2: 10uF; C_0603_1608Metric; LCSC Part C96446
C17, C18, C60: 100n; C_0603_1608Metric
D5, D6, D7, D8, D9, D10: LL4148; D_MiniMELF
D25: LED_REL1; LED_0603_1608Metric
D26: LED_REL2; LED_0603_1608Metric
D27: LED_REL3; LED_0603_1608Metric
D28: LED_REL4; LED_0603_1608Metric
D29: LED_REL5; LED_0603_1608Metric
D30: LED_REL6; LED_0603_1608Metric
J5: JP_REL4_COM_12V; PinHeader_1x02_P2.54mm_Vertical_jlc
J8: JP_REL5_COM_12V; PinHeader_1x02_P2.54mm_Vertical_jlc
J9: JP_REL6_COM_12V; PinHeader_1x02_P2.54mm_Vertical_jlc
J10: JP_REL1_COM_12V; PinHeader_1x02_P2.54mm_Vertical_jlc
J12: JP_REL2_COM_12V; PinHeader_1x02_P2.54mm_Vertical_jlc
J13: JP_REL3_COM_12V; PinHeader_1x02_P2.54mm_Vertical_jlc
J14: Conn_REL1; PinHeader_1x03_P2.54mm_Vertical_jlc
J15: Conn_REL2; PinHeader_1x03_P2.54mm_Vertical_jlc
J16: Conn_REL3; PinHeader_1x03_P2.54mm_Vertical_jlc
JP25: REL_VIN; SolderJumper-2_P1.3mm_Open_RoundedPad1.0x1.5mm
K2, K3, K4, K5, K6, K7: TIANBO-HJR-4102-L; Relay_SPDT_HJR-4102
Q2, Q3, Q4, Q5, Q6, Q7, Q15: BSS138; SOT-23
R9, R53, R54, R72, R73, R80: 20; R_0603_1608Metric
R15, R16, R17, R18, R20, R21, R22, R23, R92: 10k; R_0603_1608Metric
R71, R81, R82, R83, R84, R85: 330R; R_0603_1608Metric
R74, R75, R76, R77, R78, R79: 4k7; R_0603_1608Metric
R91: 0R; R_0603_1608Metric
R93: 100k; R_0603_1608Metric
U10: 74HC595; SOIC-16_3.9x9.9mm_P1.27mm
U20: HC 151; SOIC-16_3.9x9.9mm_P1.27mm
X5: Conn_Rel2; PhoenixContact_MCV_1,5_9-G-3.81_1x09_P3.81mm_Vertical
X6: Conn_Rel1; PhoenixContact_MCV_1,5_9-G-3.81_1x09_P3.81mm_Vertical

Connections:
+3V3: C17.1, C60.1, R22.1, R23.2, R74.2, R75.2, R76.2, R77.2, R78.2, R79.2, R93.2, U10.16 (VCC), U20.16 (VCC); also elsewhere on the board
+5V: R91.2; also elsewhere on the board
/H_CLK: U10.11 (SRCLK); also elsewhere on the board
/H_MOSI: U10.14 (SER); also elsewhere on the board
/INPUT/IO_DI_PL: R92.1, U10.12 (RCLK); also elsewhere on the board
/OUTPUT/IO_DATA_IN: U10.9 (QH')
/OUTPUT/REL1: R9.2, R71.1, U10.15 (QA)
/OUTPUT/REL1_COM: J10.1, K2.12, X6.8
/OUTPUT/REL1_NC: J14.3, K2.7
/OUTPUT/REL1_NC_TACHO: J14.2, X6.7
/OUTPUT/REL1_NO: K2.6, X6.9
/OUTPUT/REL2: R53.2, R81.1, U10.1 (QB)
/OUTPUT/REL2_COM: J12.1, K3.12, X6.5
/OUTPUT/REL2_NC: J15.3, K3.7
/OUTPUT/REL2_NC_TACHO: J15.2, X6.4
/OUTPUT/REL2_NO: K3.6, X6.6
/OUTPUT/REL3: R54.2, R82.1, U10.2 (QC)
/OUTPUT/REL3_COM: J13.1, K4.12, X6.2
/OUTPUT/REL3_NC: J16.3, K4.7
/OUTPUT/REL3_NC_TACHO: J16.2, X6.1
/OUTPUT/REL3_NO: K4.6, X6.3
/OUTPUT/REL4: R72.2, R83.1, U10.3 (QD)
/OUTPUT/REL4_COM: J5.1, K5.12, X5.8
/OUTPUT/REL4_NC: K5.7
/OUTPUT/REL4_NO: K5.6, X5.9
/OUTPUT/REL5: R73.2, R84.1, U10.4 (QE)
/OUTPUT/REL5_COM: J8.1, K6.12, X5.5
/OUTPUT/REL5_NC: K6.7
/OUTPUT/REL5_NO: K6.6, X5.6
/OUTPUT/REL6: R80.2, R85.1, U10.5 (QF)
/OUTPUT/REL6_COM: J9.1, K7.12, X5.2
/OUTPUT/REL6_NC: K7.7
/OUTPUT/REL6_NO: K7.6, X5.3
/OUTPUT/TACHO1: J14.1, R74.1, U20.4 (I0)
/OUTPUT/TACHO2: J15.1, R75.1, U20.3 (I1)
/OUTPUT/TACHO3: J16.1, R76.1, U20.2 (I2)
/OUTPUT/TACHO4: R77.1, U20.1 (I3), X5.7
/OUTPUT/TACHO5: R78.1, U20.15 (I4), X5.4
/OUTPUT/TACHO6: R79.1, U20.14 (I5), X5.1
/OUTPUT/T_ADDR0: U10.6 (QG), U20.11 (S0)
/OUTPUT/T_ADDR1: U10.7 (QH), U20.10 (S1)
/OUTPUT/VCC_REL: D5.1 (K), D6.1 (K), D7.1 (K), D8.1 (K), D9.1 (K), D10.1 (K), JP25.2 (B), K2.5, K3.5, K4.5, K5.5, K6.5, K7.5, R91.1
/TACHO: U20.5 (Q); also elsewhere on the board
/T_ADDR2: U20.9 (S2); also elsewhere on the board
GND: C2.2, C17.2, C18.2, C60.2, D25.1 (K), D26.1 (K), D27.1 (K), D28.1 (K), D29.1 (K), D30.1 (K), Q2.2 (S), Q3.2 (S), Q4.2 (S), Q5.2 (S), Q6.2 (S), Q7.2 (S), Q15.2 (S), R15.2, R16.2, R17.2, R18.2, R20.2, R21.2, R92.2, U10.8 (GND), U20.7 (~E), U20.8 (GND); also elsewhere on the board
unnamed: D5.2 (A), K2.8, Q2.3 (D)
unnamed: D6.2 (A), K3.8, Q3.3 (D)
unnamed: D7.2 (A), K4.8, Q5.3 (D)
unnamed: D8.2 (A), K5.8, Q6.3 (D)
unnamed: D9.2 (A), K6.8, Q7.3 (D)
unnamed: D10.2 (A), K7.8, Q4.3 (D)
unnamed: D25.2 (A), R71.2
unnamed: D26.2 (A), R81.2
unnamed: D27.2 (A), R82.2
unnamed: D28.2 (A), R83.2
unnamed: D29.2 (A), R84.2
unnamed: D30.2 (A), R85.2
unnamed: Q2.1 (G), R9.1, R15.1
unnamed: Q3.1 (G), R16.1, R53.1
unnamed: Q4.1 (G), R21.1, R80.1
unnamed: Q5.1 (G), R17.1, R54.1
unnamed: Q6.1 (G), R18.1, R72.1
unnamed: Q7.1 (G), R20.1, R73.1
unnamed: Q15.3 (D), R23.1, U10.13 (~OE)
unnamed: C18.1, R22.2, U10.10 (~SRCLR)
V_IN: J5.2, J8.2, J9.2, J10.2, J12.2, J13.2, JP25.1 (A); also elsewhere on the board

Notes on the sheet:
Je nach Relaistyp kann eine Spulenspannung von 5V oder 12V gewählt werden. Wichtig hierfür ist, dass die Bestückung der DC/DC auf Seite 1 beachtet wird.
12V Eingangsspannung auf COM des Relais
J15 - J16: NC des Relais oder Tachosignal auf Stecker

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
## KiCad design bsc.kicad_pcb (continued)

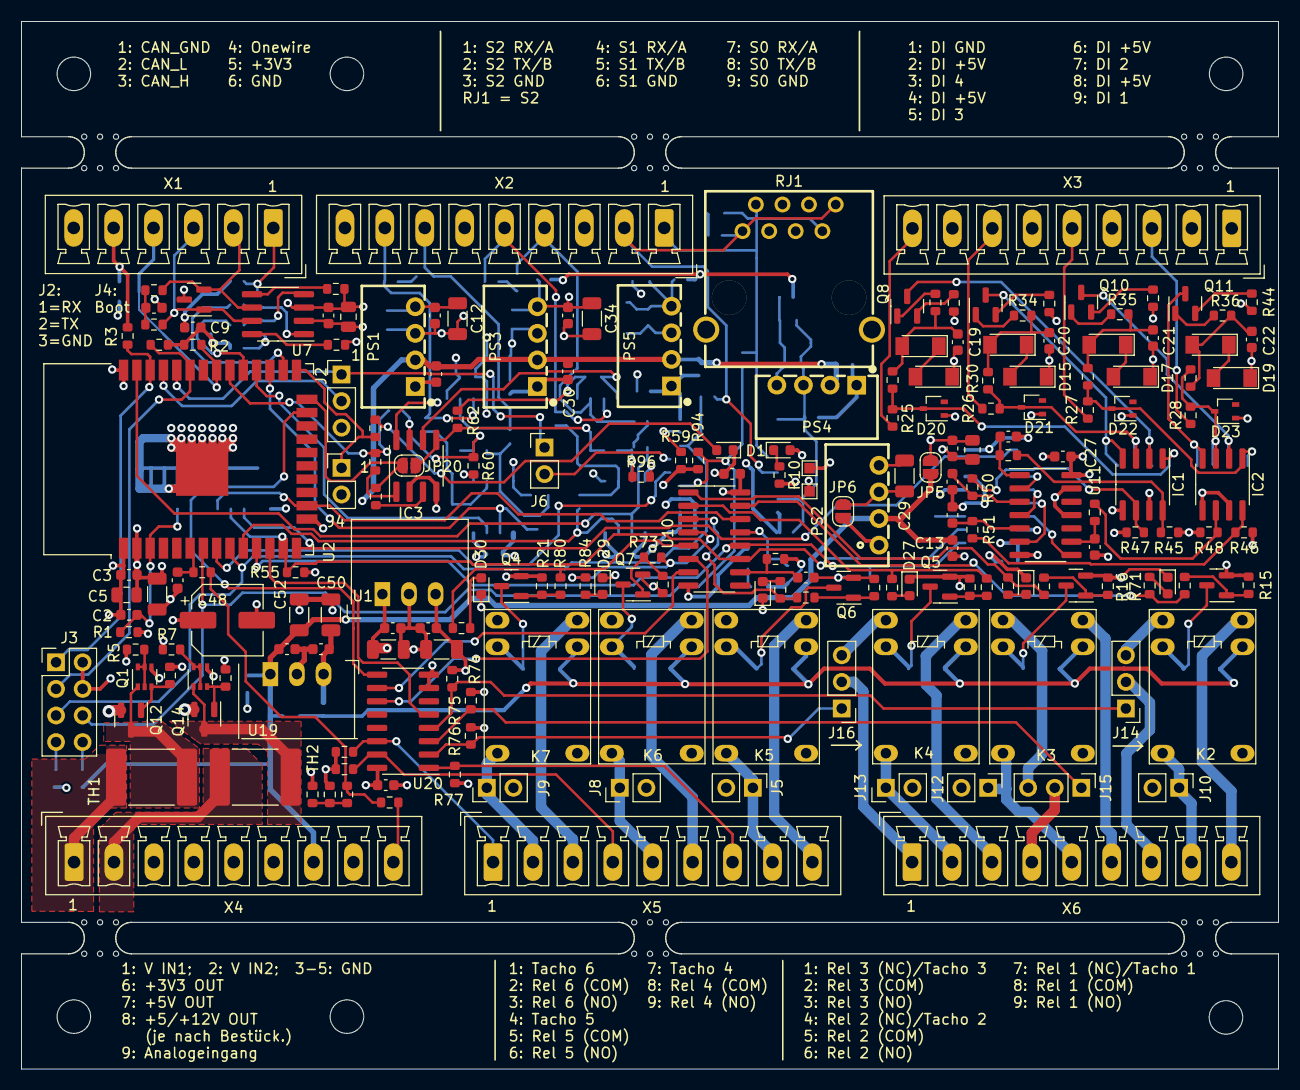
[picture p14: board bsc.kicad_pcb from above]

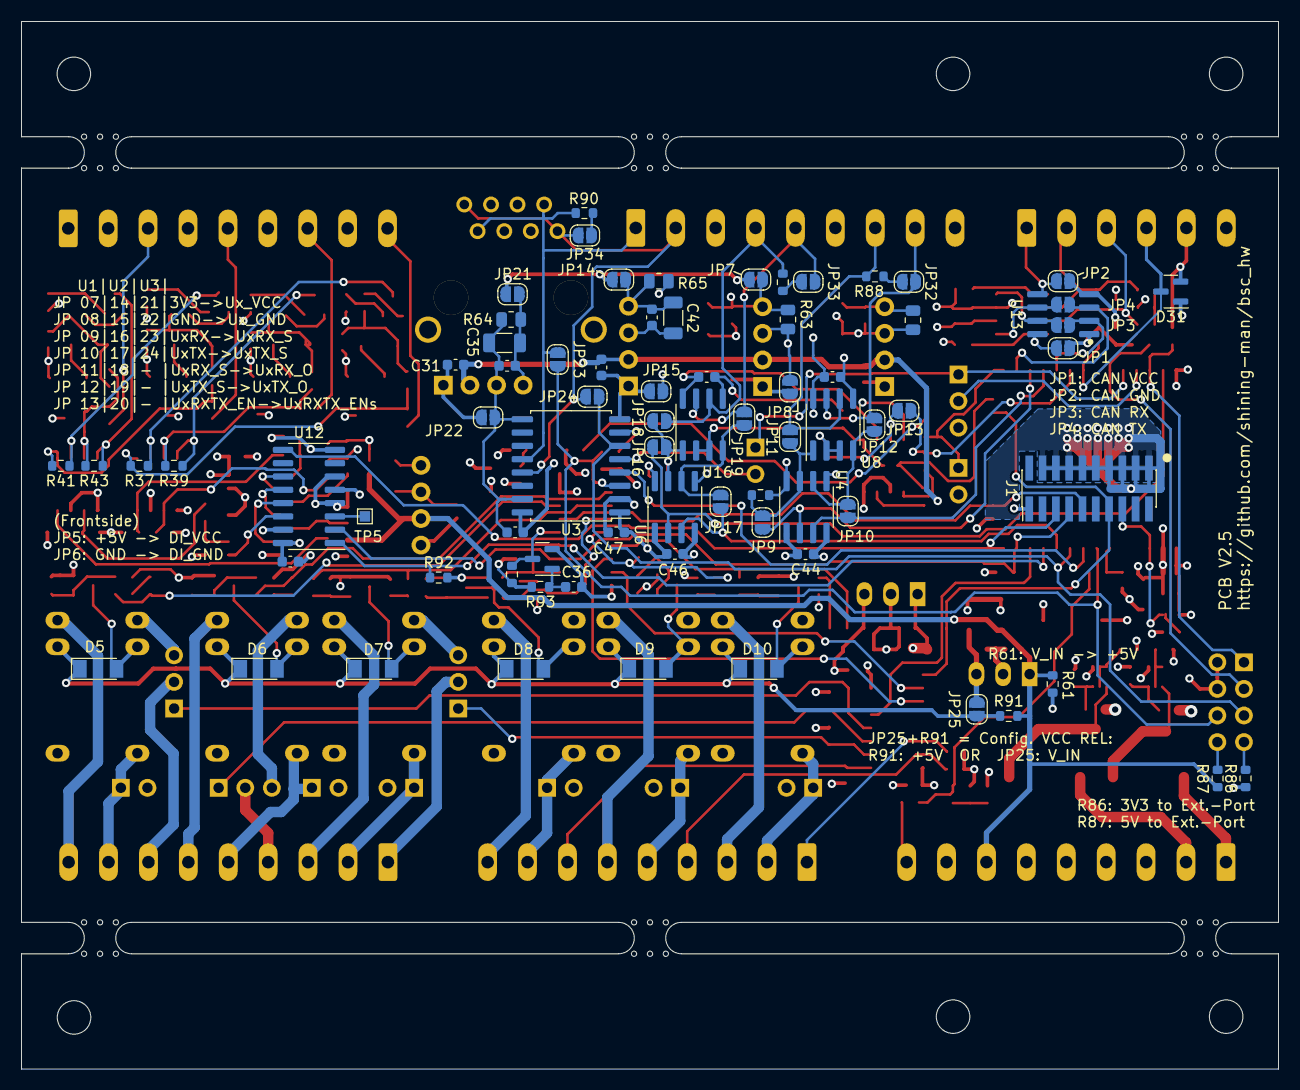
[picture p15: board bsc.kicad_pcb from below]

Board: 4 copper layers, 120.0 x 100.0 mm, 286 parts (75 on the bottom side), 175 nets.

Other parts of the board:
C36: 10uF; C_0603_1608Metric
mouse-bite-3mm-slot, mouse-bite-3mm-slot#2, mouse-bite-3mm-slot#3, mouse-bite-3mm-slot#4, mouse-bite-3mm-slot#5, mouse-bite-3mm-slot#6: VAL**; mouse-bite-3mm-slot

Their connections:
GND: C36.2; also elsewhere on the board

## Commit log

2022-10-20 Initial version
    [bsc.kicad_pcb, bsc.kicad_sch, io.kicad_sch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]
2022-11-29 Redesign PCB
    [ai.kicad_sch, bsc.kicad_pcb, bsc.kicad_sch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]
2022-12-17 Layout optimized
    [ai.kicad_sch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]
2023-04-01 Change extension bus
    [ai.kicad_sch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]
2023-07-21 Ref 2.4
    [ai.kicad_sch, bsc.kicad_pcb, bsc.kicad_sch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]
2023-11-23 Improvements added (Ref 2.4.1)
    [ai.kicad_sch, bsc.kicad_pcb, bsc.kicad_sch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]
2023-11-23 Track spacing in layout corrected
    [bsc.kicad_pcb]
2023-12-16 Slikscreen changed
    [bsc.kicad_pcb]
2024-03-25 Fix pullup
    [bsc.kicad_pcb, bsc.kicad_sch]
2024-03-29 RX Pullups von U1+U2 geändert
    [ai.kicad_sch, bsc.kicad_pcb, bsc.kicad_sch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]
2024-04-07 Version geändert
    [ai.kicad_sch, bsc.kicad_pcb, bsc.kicad_sch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]
2024-04-17 Layoutänderungen
    [ai.kicad_sch, bsc.kicad_pcb, bsc.kicad_sch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]
